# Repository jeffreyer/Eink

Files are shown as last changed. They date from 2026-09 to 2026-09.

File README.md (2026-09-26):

# MiniEink

**ESP32-C3 墨水屏设备固件** · 多屏适配 · Lua 模块化 · BLE 配置 · 深度休眠异步刷屏

> **English TL;DR** — Firmware for a small ESP32-C3 e-paper gadget. It drives three 1.54"
> panels (4-color 200x200 / 6-color 240x240 / black-white 200x200 SSD1681 with partial
> refresh), is configured over BLE from a WeChat mini program, runs user-installed Lua
> modules (gallery, quotes, countdown, calendar, tarot, ...), and uses a deep-sleep-first
> power model: the MCU issues the refresh command and sleeps immediately, waking only to
> power the panel down.

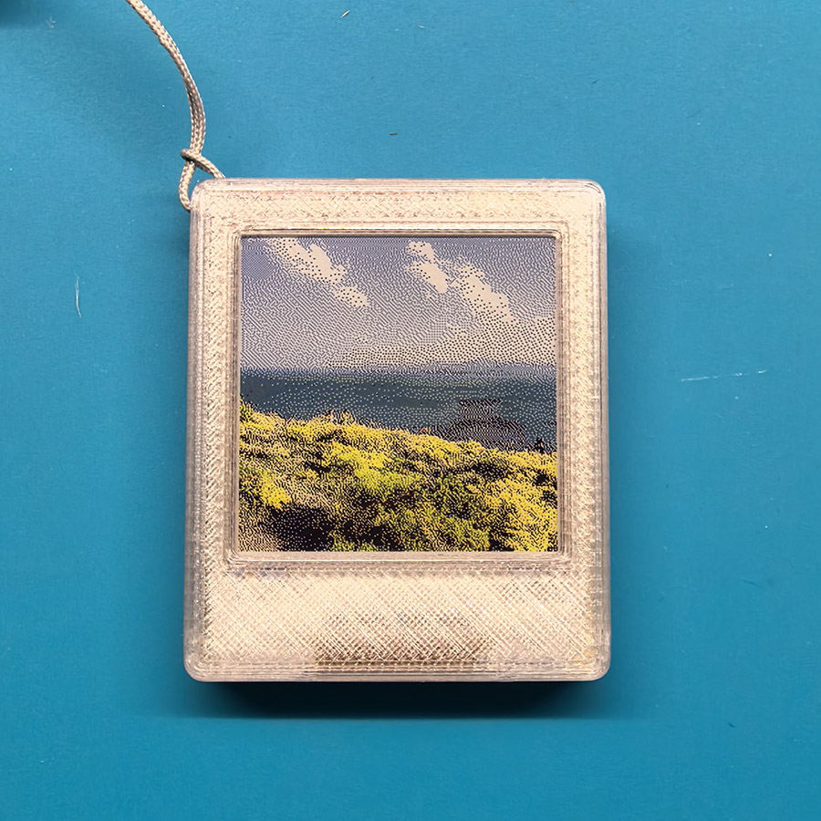
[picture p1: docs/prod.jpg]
 
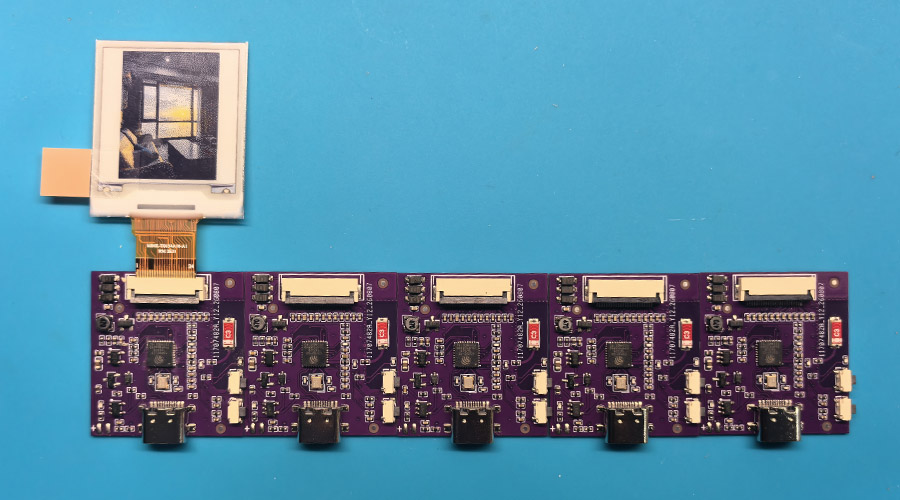
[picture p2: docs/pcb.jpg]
 
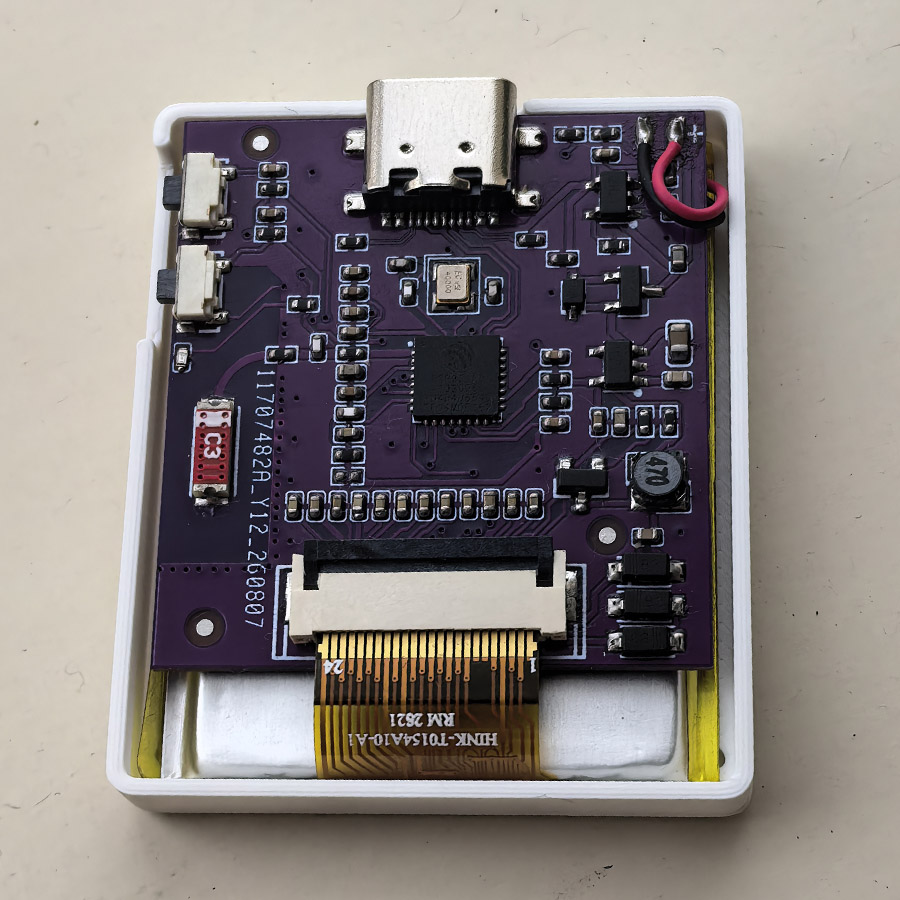
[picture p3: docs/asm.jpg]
 

---

## 目录

- [1. 项目简介](#1-项目简介)
- [2. 特性](#2-特性)
- [3. 硬件](#3-硬件)
- [4. 目录结构](#4-目录结构)
- [5. 快速开始](#5-快速开始)
- [6. 使用说明](#6-使用说明)
- [7. Lua 模块开发](#7-lua-模块开发)
- [8. 省电设计](#8-省电设计)
- [9. 分区表](#9-分区表)
- [10. 已知限制](#10-已知限制)
- [11. 第三方组件与许可](#11-第三方组件与许可)
- [12. 相关文档](#12-相关文档)
- [免责声明](#免责声明)
- [License](#license)

---

## 1. 项目简介

MiniEink 是一个基于 ESP32-C3 的多色墨水屏设备。设备平时处于**深度休眠**，休眠电流28uA，异步刷屏非常省电，靠按键或定时唤醒。所有交互（切换模块/条目、安装模块、改配置、上传图片）都通过 **BLE** 由微信小程序完成。

本项目包含设备源码/外壳3D设计和硬件设计全部开源文件。

## 2. 特性

**硬件**

- 外观尺寸：43\*36\*8.5mm
- 续航：200mA，休眠28uA，每次刷新40uA，每小时刷新一次，可续航4个月左右

**屏幕**

- 一套代码支持三种 1.54" 墨水屏，靠一个宏切换（见 3.2）
- 统一的显示接口：初始化、整帧刷新、刷白
- **异步刷屏**：发完刷新命令立即深度休眠，刷新结束后定时唤醒补断电——刷新期间的 MCU 电流从约 18 mA 降到接近 0
- **黑白屏局部刷新**：面板比对上一帧只驱动变化像素，约 0.3 s（全刷约 2s），不整屏闪黑；变化过大或连续局部刷到上限时自动全刷清残影
- **4色/6色屏刷新**：4色屏刷新约12秒，6色屏刷新约26秒
- 内置 GB2312 全量点阵字库（16x16 / 24x24），Lua 侧可直接显示中文

**系统**

- 模块化：内置相册 + 动态 **Lua 模块**，模块可启用/禁用、按键切换、定时唤醒刷新
- 统一休眠模型：任何模块执行完即休眠，没有常驻 `loop`，功耗可预期
- BLE 配置（NimBLE）：状态查询、模块安装、配置读写、图片上传/下载、校时
- 相册：图片存 SPIFFS，支持显示方向、循环播放、按键手动翻页
- 电池检测与低压保护（< 3.1 V 直接休眠）
- 省电细节：日常深度休眠、tickless idle / light sleep、BLE 断开即休眠、PWM 指示灯

## 3. 硬件

### 3.0 硬件制作注意事项

- Gerber.rar为已验证项目，直接打样即可，PCB厚度0.8mm
- 工程文件修改PCB挖空TypeC区域使用了TypeC沉板接口设计，厚度进一步降低0.8mm，但未作打样验证
- 如果使用6色屏请不要焊接R18电阻
- 参考上述图片组装硬件，最后胶水粘合上下外壳

### 3.1 规格与引脚

| 项目 | 规格 |
|---|---|
| 主控 | ESP32-C3（4 MB Flash，无 PSRAM） |
| 屏幕 | 1.54" 墨水屏，三种可选（见 3.2） |
| 按键 | KEY_UP / KEY_DOWN，低电平有效，可从深度休眠唤醒 |
| 指示灯 | 蓝色蓝牙开启 LED |
| 电池 | 3.85V 高压锂电，充满4.35V，ADC 分压采样（分压系数 2），< 3.1 V 保护性休眠 |
| 通信 | BLE 5（NimBLE-Arduino） |

| 信号 | GPIO |
|---|---|
| KEY_UP | 1 |
| KEY_DOWN | 2 |
| 电池 ADC | 0（ADC1_CH0） |
| EPD BUSY | 10 |
| EPD RST | 3 |
| EPD DC | 4 |
| EPD CS | 5 |
| EPD SCK | 6 |
| EPD MOSI | 7 |
| 蓝色 LED | 20 |

三种屏共用同一组 EPD 引脚，换屏只需改 `include/common.h` 的宏。

### 3.2 屏幕型号

| 型号 | 宏（`include/common.h`） | 分辨率 / 色深 | 帧大小 | 驱动 |
|---|---|---|---|---|
| 4 色（黑白黄红） | 两个宏都不定义 | 200x200 / 2bpp | 10000 B | `eink.cpp` + `Display_EPD_W21*.cpp` |
| 6 色（+蓝绿） | `#define INK6` | 240x240 / 4bpp | 28800 B | `eink6.cpp`（JD7601） |
| 黑白 | `#define INK_BW` | 200x200 / 1bpp | 5000 B | `eink_bw.cpp`（SSD1681，支持局部刷新） |

屏幕色数会通过 BLE 状态的 `ink` 字段上报（6 / 4 / 2），小程序据此选择图片格式。

## 4. 目录结构

```
src/
├── main.cpp              # 入口：按键扫描、唤醒判定、主循环
├── sleep_manager.cpp     # 深度休眠：唤醒源（按键/定时）与定时器配置
├── epd_async.cpp         # 异步刷屏调度：刷新中标记、补断电、兜底断电
├── eink.cpp / eink6.cpp / eink_bw.cpp   # 4 色 / 6 色 / 黑白屏驱动
├── Display_EPD_W21*.cpp  # 4 色屏底层时序
├── GUI/                  # GUI_Paint 绘图库（Scale 2/4/7 对应 1/2/4 bpp）
├── module_registry.cpp   # 模块注册表：内置模块 + 扫描 /spiffs 下的 Lua 模块
├── lua_hardware_api.cpp  # Lua 侧 API：display / time / config / sys
├── gallery.cpp           # 相册模块（列表、显示、旋转、循环）
├── ble_config.cpp        # BLE 服务：状态、配置、模块/图片上传、校时
├── battery.cpp           # 电池 ADC 采样与低压保护
├── cmd_handler.cpp       # 串口调试命令
└── time_calibration.cpp  # RTC 校时与时区保持

include/                  # 头文件（eink_display.h / epd_async.h / common.h ...）
lib/lua-5.4.7/            # Lua 解释器源码
data/                     # 烧录到 SPIFFS（modules 分区）
├── fonts/                # GB2312 16/24 点阵 + Unicode→GB2312 映射表
└── gallery.cfg           # 相册模块的配置定义
docs/LUA_SCRIPT_GUIDE.md  # Lua 模块开发与 API 完整文档
tools/                    # 字库生成、平台补丁等脚本
partitions.csv            # 分区表
platformio.ini            # PlatformIO 工程配置
PROJECT_HANDOFF.md        # 开发手记（中文，含大量实现细节与踩坑记录）
```

## 5. 快速开始

### 5.1 环境要求

- [PlatformIO](https://platformio.org/)（VSCode 插件或 Core CLI 6.x）
- Python 3（PlatformIO 自带；`tools/` 下的字库脚本需要 `Pillow`，仅重新生成字库时用到）
- 一块 ESP32-C3 设备（本项目用 `board = adafruit_qtpy_esp32c3` 作为板级变体，硬件为自定义板）

### 5.2 首次构建：给平台打补丁

工程用 `custom_sdkconfig` 打开电源管理 / tickless idle，pioarduino 平台在该配置下有两处
构建 bug（`lib_ignore = BLE` 会剪掉 IDF 的 bt 组件、库构建子环境读不到 `lib_deps`），
首次构建前先运行补丁脚本（可重复执行、可还原）：

```bash
python tools/pioarduino_patches.py            # 打补丁
python tools/pioarduino_patches.py --dry-run  # 只检查状态
python tools/pioarduino_patches.py --revert   # 还原
```

> 平台版本被 `platformio.ini` 固定在 pioarduino 55.03.38-1；升级平台后若脚本提示文本
> 不匹配，需要按脚本输出手工处理。

### 5.3 编译与烧录

```bash
pio run                        # 编译固件
pio run -t upload              # 烧录固件（USB）
pio run -t uploadfs            # 烧录文件系统：data/ → SPIFFS（modules 分区）
pio device monitor -b 115200   # 串口日志 / 调试命令
```

> 首次编译会按 `custom_sdkconfig` 全量重建 Arduino IDF 库，耗时较长（之后走缓存）。

要点：

- **固件和文件系统都要烧**：字库与配置定义在 `data/`，通过 `uploadfs` 写入 SPIFFS；
  只烧固件会出现中文显示为 `?`、模块没有配置项等问题。
- 修改 `data/` 后重新执行 `uploadfs` 会覆盖整个分区，设备上已上传的模块与相册图片
  请先备份（`pio run -t uploadfs` 不做合并）。
- 设备上运行时上传的模块与图片也都在同一块 SPIFFS 里，见 [第 9 节](#9-分区表)。

### 5.4 中文字库

`data/fonts/` 三个文件在运行时由 `lua_hardware_api.cpp` 直接读取：

| 文件 | 内容 |
|---|---|
| `gb2312_16.bin` | GB2312 全集 16x16 点阵，每字 32 B |
| `gb2312_24.bin` | GB2312 全集 24x24 点阵，每字 72 B |
| `gb2312_map.bin` | Unicode → GB2312 映射表（`[u32 count][count x (u16 u16)]`，按 Unicode 升序） |

重新生成（两个脚本二选一，输出都写到 `data/fonts/`）：

```bash
# A. 用 TTF 字体渲染（可换任意中文字体）
python tools/gen_gb2312_font.py --font C:/Windows/Fonts/NotoSansSC-VF.ttf

# B. 经典 HZK16 / HZK24S 点阵字库转换（源文件需自行准备，未随仓库发布）
python tools/convert_hzk.py tools/fonts/hzk_src/HZK16_ucdos.bin  data/fonts/gb2312_16.bin  32
python tools/convert_hzk.py tools/fonts/hzk_src/HZK24S_ucdos.bin data/fonts/gb2312_24.bin  72
```

## 6. 使用说明

### 6.1 按键

| 按键 | 短按 | 长按（按住 3 秒即触发） |
|---|---|---|
| KEY_UP | 上一项 | 开/关 BLE 配置模式 |
| KEY_DOWN | 下一项 | 切换到下一个已启用模块 |

设备默认深度休眠，按键可唤醒；唤醒后执行动作即再次休眠（BLE 配置模式除外）。

### 6.2 串口调试命令

| 命令 | 说明 |
|---|---|
| `ver` | 固件版本 + 编译时间 |
| `bat?` | 电池电压（mV） |
| `gettime?` | 当前时间 |
| `lsmod` | 列出已注册模块（类型 / 配置项数 / 是否启用） |
| `lsi` / `ls` | 列出 `/spiffs` / `/extflash` 文件 |
| `read <文件名>` | 打印 `/spiffs/<文件名>` 内容 |
| `rm <文件名>` | 删除 `/spiffs/<文件名>` |
| `dis <文本>` | 在屏幕上显示一段文本（验证屏幕与字库） |
| `white` | 整屏刷白 |
| `probe` | 打印面板 BUSY 电平时间线（适配新屏幕时测刷新时长与空闲极性） |
| `nvs` | 打印 NVS 中的键值 |
| `unbind` | 清除 BLE 绑定并重新生成密码 |
| `dfu` | 重启进入 ROM 下载模式（等同拉低 GPIO0 复位） |

### 6.3 通过 BLE 使用

1. 长按 KEY_UP 进入 BLE 配置模式（蓝色指示灯闪烁），设备以 `MiniEink` 广播；
2. 使用微信小程序*幻彩抽屉*连接；
3. 认证后即可查询状态、读写配置、安装 Lua 模块、上传相册图片；
4. 断开连接后设备立即深度休眠。

## 7. Lua 模块开发

模块 = 一个 `.lua` 脚本 + 可选的同名 `.cfg` 配置定义，放在 data 目录（`/data/<id>.lua`、`/data/<id>.cfg`），并通过上传文件系统命令传输到设备，设备启动时会扫描并注册为模块。
还可通过小程序市场下载安装，在小程序配置页启用/禁用。

```lua
-- @name: 纪念日倒计时
-- @version: 1.0.0
-- @author: your-name
-- @description: 显示距离目标日期的天数
-- @id: countdown

function setup()
  display.clear()
  display.text(10, 20, "距离目标还有", 3, 0)
  display.text(10, 60, "128 天", 4, 3)
  display.show()          -- 异步刷屏：发完刷新命令即可返回
end

-- 按键钩子（可选）：短按 KEY_UP / KEY_DOWN 时调用
function subpage_prev() end
function subpage_next() end
```

要点：

- `setup()` 每次唤醒（定时/按键）都会被调用一次，**画完请调用 `display.show()`**；
  模块的 `loop()` 不会被调用（统一休眠模型），周期刷新用配置项 `interval`
  （分钟，1~1440）交给系统定时唤醒。
- 屏幕尺寸由设备注册为全局量 `WIDTH` / `HEIGHT`（黑白屏与 4 色屏 200，6 色屏 240）。
- 颜色值统一为 `0=黑 1=白 2=黄 3=红 4=蓝 5=绿`；4 色与黑白屏会自动做合理映射
  （黑白屏把黄色映射为浅灰抖动，红/蓝/绿映射为黑）。
- 跨深度休眠的状态用 `sys.set_state()` / `sys.get_state()`（RTC 内存，掉电丢失）。
- 配置项读写用 `config.get()`；键名同时是 NVS 键名，**最长 15 字符**。

完整 API（`display.*` / `time.*` / `config.*` / `sys.*`、中文字库与排版注意事项）见
[`docs/LUA_SCRIPT_GUIDE.md`](docs/LUA_SCRIPT_GUIDE.md)。

配置定义 `.cfg`（决定小程序配置页渲染哪些控件）为 JSON 数组：

```json
[
  {
    "type": "select",
    "key": "interval",
    "label": "自动刷新",
    "options": [
      {"label": "关闭", "value": 0},
      {"label": "6小时", "value": 360}
    ],
    "default": 360
  }
]
```

## 8. 省电设计

**统一休眠模型**：设备没有常驻循环，模块执行完即 `esp_deep_sleep_start()`；唤醒源只有
按键（KEY_UP / KEY_DOWN）与定时器（模块配置的 `interval`）。蓝牙配置模式是唯一例外，
断开连接后立即休眠。

**异步刷屏**（`include/epd_async.h`）：墨水屏刷新由面板自己定时序，MCU 等待毫无意义。
所以流程是：

1. 模块调用 `display.show()` → 驱动发完刷新命令立即返回，并置一个 RTC 标记；
2. `enter_deep_sleep()` 看到该标记：只启用定时唤醒（禁按键唤醒，避免打断刷新），MCU 立刻休眠；
3. 定时唤醒后只做一件事：等刷新结束 → 关面板电源 → 面板深度休眠 → 继续休眠；
4. 若刷完没有休眠（例如 BLE 交互中）：主循环兜底，刷新结束后补一次断电。

| 屏型 | 刷新耗时 | 补断电唤醒窗口 |
|---|---|---|
| 6 色 240x240 | 20~30 s | 30 s |
| 4 色 200x200 | ~13.5 s | 22 s |
| 黑白全刷 | ~2 s | 4 s |
| 黑白局部刷 | ~0.3 s | 1.5 s |

深度休眠期间会 `gpio_hold` 住面板控制引脚（RST / DC / CS / SCK / MOSI），避免引脚浮空
干扰面板；唤醒补断电前先做一次“只复位、不等 BUSY”的复位，保证断电/深睡命令不被忽略。

**局部刷新（黑白屏）**：上一帧缓存在 RTC 内存（5000 B，带 CRC 校验），每次刷新把新帧写
`0x24`、上一帧写 `0x26` 作为基准，然后发 `0x22=0xCF` 局部刷新——面板只驱动有差异的像素。
变化像素超过 25%（`EPD_BW_PARTIAL_MAX_DIRTY_PCT`）或连续局部刷满 10 次
（`EPD_BW_PARTIAL_MAX_RUN`）时自动改走全刷清残影；阈值都在 `include/eink_bw.h`，
可按实测调整。

**其他**：`CONFIG_PM_ENABLE` + tickless idle 让 BLE 广播/等待期间自动进入 light sleep；
BUSY 轮询间隔 ≥ 20 ms 才能让 CPU 睡进 light sleep；指示灯用 1 kHz / 5% PWM 代替常亮。

## 9. 分区表

`partitions.csv`（4 MB Flash）：

| 分区 | 类型 | 偏移 | 大小 | 用途 |
|---|---|---|---|---|
| `nvs` | data/nvs | 0x9000 | 20 KB | 配置、绑定状态、密码 |
| `otadata` | data/ota | 0xE000 | 8 KB | 预留 |
| `app0` | app/ota_0 | 0x10000 | 992 KB | 固件 |
| `modules` | data/spiffs | 0x108000 | 约 3.0 MB | SPIFFS：字库、模块 `.lua/.cfg`、相册图片 |

## 10. 已知限制

- 局部刷新目前只有**黑白屏**支持；4 色与 6 色驱动仍是整屏刷新。
- 换屏幕型号后，相册里旧格式的图片无法显示（设备按字节数校验并拒绝），需要重新上传。
- 局部刷新会积累残影，因此有“每 N 次 / 变化过大自动全刷”的策略，做不到“永不闪屏”。
- 部分面板的 BUSY 引脚在读不到空闲电平（例如 MCU 深睡醒来后一直为低），因此补断电逻辑
  以时间为保证、不依赖 BUSY；`probe` 命令可用于确认某块屏的 BUSY 行为。
- 当前固件只有一个 app 分区，**不支持 OTA**，升级需要重新烧录。

## 11. 第三方组件与许可

| 组件 | 说明 / 许可 |
|---|---|
| [Lua 5.4.7](lib/lua-5.4.7) | 源码在 `lib/lua-5.4.7`，MIT |
| [NimBLE-Arduino](https://github.com/h2zero/NimBLE-Arduino) | BLE 栈，Apache-2.0（PlatformIO 依赖） |
| [FastLED](https://github.com/FastLED/FastLED) | PlatformIO 依赖，MIT |
| GUI_Paint / 4 色屏时序 | 面板原厂示例代码（Good Display 系列），保留原貌 |
| 6 色（JD7601）/ 黑白（SSD1681）驱动 | 由面板原厂示例移植（含初始化时序与波形表） |
| `data/fonts/*.bin` | 由经典 HZK16 / HZK24S 点阵字库转换（来源见 `tools/convert_hzk.py`） |

## 12. 相关文档

- [`docs/LUA_SCRIPT_GUIDE.md`](docs/LUA_SCRIPT_GUIDE.md)：Lua 模块开发完整指南
  （模块格式、`display`/`time`/`config`/`sys` API、中文字库与排版注意事项）
- [`PROJECT_HANDOFF.md`](PROJECT_HANDOFF.md)：开发手记，含屏幕适配、省电实测、
  BLE 分块传输、小程序前端交互等实现细节与踩坑记录（中文）
- `python tools/pioarduino_patches.py --dry-run`：检查构建平台补丁状态

## 免责声明

本项目是个人自制的开源固件工程，按“现状”提供，不保证适用于任何特定用途。自行打样、
焊接、连接锂电池时请注意安全（保护板、极性、避免短路），因使用本工程造成的设备损坏或
数据丢失由使用者自行承担。

## License
- 固件代码: GPLv3
- 硬件设计: CC BY-NC-SA 4.0

商业使用需获得作者书面许可。

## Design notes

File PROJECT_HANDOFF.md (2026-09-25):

# 项目交接文档 - MiniEink墨水屏设备

## 项目概述

这是一个基于ESP32-C3的墨水屏设备项目，包含设备端固件和微信小程序前端。设备通过BLE与小程序通信，支持模块化配置和相册管理功能。

**设备型号**: MiniEink (Adafruit QT Py ESP32-C3)  
**显示屏**: 三个版本（`include/common.h` 中三选一）
- 4色屏（都不定义宏）：200x200 2bpp（黑、白、黄、红）
- 6色屏（`INK6` 宏）：1.54寸 240x240 JD7601 4bpp（黑、白、黄、红、蓝、绿）
- 黑白屏（`INK_BW` 宏）：1.54寸 200x200 SSD1681 1bpp（黑、白）
  - **当前为 6 色屏模式（`#define INK6` 已开启）**；换黑白屏注释 `INK6`、打开 `INK_BW`
  - 三个驱动各自整体由宏保护（文件顶部先 `#include "common.h"` 才能看到宏），
    同一时刻只有一个驱动参与编译，避免重复定义 `BlackImage`/`gui_drawtext`
**刷新时间**: 黑白约2秒；4色约12秒；6色约30-40秒（驱动内 BUSY 超时上限 40 秒）。
三者都走异步刷屏：发出刷新命令后 MCU 立刻深度休眠，刷新结束由定时唤醒补断电  
**通信方式**: BLE (NimBLE)  
**开发环境**: PlatformIO + Arduino Framework  
**前端**: 微信小程序

---

## 6色屏适配（当前主线）

新版硬件：6色 1.54寸 240x240 墨水屏（JD7601 驱动，4bpp 打包，每字节 2 像素），
并新增 KEY_UP / KEY_DOWN 两个实体按键。固件通过 `include/common.h` 中的 `#define INK6`
区分 6 色 / 4 色编译模式。

### 引脚（6色屏）

| 信号 | GPIO |
|---|---|
| KEY_UP | 1 |
| KEY_DOWN | 2 |
| BLE_LIGHT | 20 |
| EPD BUSY | 10 |
| EPD RST | 3 |
| EPD DC | 4 |
| EPD CS | 5 |
| EPD SCK | 6 |
| EPD MOSI | 7 |

### 颜色编码（设备端，与 JD7601 面板码一致）

| 颜色 | 半字节(nibble) | 字节(2像素) |
|---|---|---|
| 黑 | 0x0 | 0x00 |
| 白 | 0x1 | 0x11 |
| 黄 | 0x2 | 0x22 |
| 红 | 0x3 | 0x33 |
| 蓝 | 0x5 | 0x55 |
| 绿 | 0x6 | 0x66 |

**前端色板校准**（`image-editor.js getPalette()` / `imageProcessor.js rgbTo6ColorCode()`，
用于预览显示与误差扩散的目标色，非设备端帧码）：

| 颜色 | 名义值 | 校准值（实拍6色条估计） |
|---|---|---|
| 白 | 255,255,255 | 240,238,228（暖白） |
| 黑 | 0,0,0 | 25,25,30 |
| 红 | 255,0,0 | 210,65,48（偏暗砖红） |
| 黄 | 255,255,0 | 235,230,55 |
| 蓝 | 0,0,255 | 23,100,182（偏暗藏蓝） |
| 绿 | 0,128,0 | 50,118,88（偏橄榄） |

### 绘制与刷新链路

- 画布：`BlackImage[28800]`（240x240，4bpp），由 `eink6.cpp` 定义
- 绘制：复用 `GUI_Paint` 的 `Paint_SetScale(7)`（4bpp，2像素/字节，高位在前），
  与 JD7601 帧格式逐字节一致，`lua_hardware_api.cpp` 在 `INK6` 下自动切换
- 刷新：`display.show()` → `epdDisplayImage()`（写帧 0x10 → 刷新 0x12 后立即返回，
  断电与面板休眠由 `epd_async` 调度）
- 4色屏代码在 `INK6` 下通过 `#ifndef INK6` 整体跳过（`eink.cpp`）

### Lua 颜色值

`0=黑, 1=白, 2=黄, 3=红, 4=蓝, 5=绿`（4色屏仅支持 0-3）。
`WIDTH` / `HEIGHT` 全局量由固件注册，`INK6` 下自动为 240。

### 按键功能（`main.cpp check_btn`）

| 按键 | 短按 | 长按(3秒) |
|---|---|---|
| KEY_UP | 模块"上一项"钩子（`subpage_prev`，相册=上一张、名言=上一条）；无钩子则 subpage-1 | 开关 BLE 配置 |
| KEY_DOWN | 模块"下一项"钩子（`subpage_next`，相册=下一张、名言=下一条）；无钩子则 subpage+1 | 切换下一个启用模块（`module_registry_next_enabled`，按住3秒即触发，并保存当前模块） |

模块可在 `module_descriptor_t` 注册 `subpage_next/subpage_prev` 自定义按键行为
（`gallery` 注册为上一张/下一张；**Lua 模块在脚本中定义同名函数即可注册**，
如名言 `subpage_next/subpage_prev`；其他模块默认 subpage ±1，互不影响）。
统一休眠模型下，按键唤醒**不执行模块 setup**：系统记录唤醒按键，由 `check_btn`
判定短按/长按后执行对应动作并休眠（短按 → 上一项/下一项钩子，长按 → 切模块/开 BLE）。
Lua 按键钩子被调用时若模块未加载（按键唤醒跳过了 setup），系统会**只加载脚本、
不执行 setup 绘制**，再由钩子自行绘制。

### BLE 状态字段

`get_status` 回传 `"ink"` 为墨水屏色数（6 / 4 / 2），小程序据此选择图片格式
（6色：240x240 4bpp / 28,800 字节；4色：200x200 2bpp / 10,000 字节；
黑白：200x200 1bpp / 5,000 字节）。

**电量字段**：状态 JSON 只回传 `"battery_mv"`（分压后电压，分压系数2），
百分比由前端自行换算（3300mV~4200mV → 0-100%，`bluetooth.js applyBatteryPercent()`）。
首次状态请求时触发一次 ADC 采样。

---

## 墨水屏驱动（三选一）与统一接口

三种屏型通过 `include/common.h` 里的宏切换，调用点统一走 `include/eink_display.h`
暴露的接口，不再各自写条件编译：

| 屏型 | 宏 | 帧缓冲 | 驱动实现 |
|---|-----|---|---|
| 4 色 200x200 2bpp | 无 | `BlackImage[10000]` | `eink.cpp` + `Display_EPD_W21*.cpp` |
| 6 色 240x240 4bpp | `INK6` | `BlackImage[28800]` | `eink6.cpp` |
| 黑白 200x200 1bpp | `INK_BW` | `BlackImage[5000]` | `eink_bw.cpp`、`eink_bw.h` |

统一接口（各驱动的 `.cpp` 内实现，见 `include/eink_display.h`）：

- `eink_display_init()`：初始化 SPI 与面板，`setup()` 调用一次
- `eink_display_frame()`：把 `BlackImage` 整帧刷到屏幕（**异步**：发完刷新命令即返回）
- `eink_display_white()`：全屏刷白
- `extern unsigned char BlackImage[ALLSCREEN_BYTES]`：当前屏型的画布缓冲

### 异步刷屏调度层（`include/epd_async.h` + `src/epd_async.cpp`）

三种屏共用同一套“发完刷新命令就休眠”的省电机制，驱动只实现两个钩子：

| 钩子 | 作用 |
|---|---|
| `epdPanelIsIdle()` | 刷新是否已结束（读 BUSY 空闲电平） |
| `epdPanelPowerOff()` | 关闭面板电源 + 面板深度休眠（假定刷新已结束） |

调度层提供：

| 接口 | 时机 | 行为 |
|---|---|---|
| `epdAsyncMarkStarted()` | 驱动发完刷新命令后 | 置 RTC 标志，函数立即返回 |
| `epdAsyncIsPending()` | 各处判断 | 是否有刷新进行中（跨深度休眠保持） |
| `epdAsyncWaitPrevious()` | 新一帧开始前 | 上一帧未刷完先等它结束，避免 reset 打断刷新 |
| `epdAsyncPowerOffNow()` | 定时唤醒补断电 / 进 BLE 前 | 断电 → 面板休眠（**不等 BUSY**，几十毫秒返回） |
| `epdAsyncMaintain()` | 主循环 | 未休眠时兜底：刷新结束且过了延迟才断电（**非阻塞**，不拖慢 BLE） |
| `epdAsyncPrepareSleep()` | 进深度休眠前 | 刷新中则 `gpio_hold` 住面板控制脚，见下 |
| `epdAsyncReleasePins()` | 开机初始化墨水屏前 | 释放上次休眠保持的引脚 |

完整流程（三个屏型一致）：

1. 模块 `setup` 绘制 → `eink_display_frame()` 发出刷新命令 → 置标志后立即返回；
2. `enter_deep_sleep()` 发现标志：只启用 `EPD_ASYNC_REFRESH_SLEEP_S` 秒定时唤醒
   （禁用 GPIO 唤醒，避免按键中途唤醒打断刷新），MCU 立刻休眠；
3. 定时唤醒后 `setup()` 走快路径：`eink_display_init()` 只初始化总线
   （**pending 时不 reset 面板**）→ `epdAsyncPowerOffNow()` 直接断电
   （唤醒时刻按刷新时长选取，**不再依赖 BUSY 判空闲**）→ 清标志 → 继续休眠；
4. 若没休眠（BLE 交互 / 上电待机）：主循环 `epdAsyncMaintain()` 在刷新结束、
   且超过 `EPD_PANEL_POWEROFF_DELAY_MS` 后补一次断电；BUSY 读不到空闲电平时，
   到达 `EPD_ASYNC_FORCE_POWEROFF_MS` 也会兜底断电（非阻塞，不会卡住 loop）。

进入 BLE 前（`ble_config_init`）：面板没在刷新就立即断电 + 面板休眠（按键唤醒进
BLE 时面板刚 init 过，不断电会持续耗电）。这里**也不能等 BUSY**：面板处于睡眠/非
初始化态时 BUSY 一直是忙电平（实测进 BLE 时 BUSY=0，白等 3 秒），所以直接走
`epdAsyncPowerOffNow()`；正在刷新则交给主循环补断电（4 色要 13.5 秒、6 色要 30 秒，
阻塞会让 BLE 迟迟不广播）。

同理，6 色驱动断电阶段的 BUSY 等待上限从 10 秒收到 `POWEROFF_WAIT_MS`（2 秒）兜底。

注意：异步刷新窗口内**只启用定时唤醒、禁用 GPIO 唤醒**，这段时间（黑白 6 秒 /
4 色 22 秒 / 6 色 30 秒）按键不会被响应——这是为了避免按键打断刷新，代价与
6 色屏原有行为一致。

各屏参数（定义在各自驱动头文件，调度层取默认值兜底）：

| 屏型 | 全刷耗时 | `EPD_ASYNC_REFRESH_SLEEP_S` | `EPD_PANEL_POWEROFF_DELAY_MS` | `EPD_ASYNC_WAIT_TIMEOUT_MS` |
|---|---|---|---|---|
| 6 色 240x240 | 20~30s | 30 | 3000 | 5000 |
| 4 色 200x200 | ~13.5s（实测） | 22 | 13000 | 3000 |
| 黑白 200x200 | 全刷 ~2s / 局部刷 ~0.3~0.5s | 4（全刷）/ 1.5（局部刷，`EPD_BW_*_REFRESH_MS`） | 3000 | 3000 |

（`EPD_ASYNC_FORCE_POWEROFF_MS`：未休眠时的兜底断电时间，6 色 40s / 4 色 20s / 黑白 6s）

**BUSY 只是优化，时间才是保证**：定时唤醒路径完全不等 BUSY；主循环兜底路径优先看
BUSY，读不到空闲电平则按时间兜底。所以即便某块屏 BUSY 引脚不可读，也不会出现长时间
卡住或面板一直通电。

**四色板实测（`probe` 命令 + 唤醒探针）**：醒着刷一次全白 **13.5 秒**完成
（BUSY 忙=0 / 空闲=1，极性正确、引脚正常）；但 MCU 深度休眠期间面板控制 IC 会
进入非初始化状态，唤醒后 BUSY 一直为 0，**而屏幕内容显示正确**（墨水屏双稳态，
图像不依赖 IC 供电/状态）。因此四色屏的补断电流程改为：

1. 唤醒后不等 BUSY，也不做整屏初始化（`lcd_chkstatus()` 是死等，绝不能进）；
2. `EPD_reset_only()` 只做一次复位（不等 BUSY），把控制 IC 拉回已知状态；
3. `EPD_poweroff_sleep()` 发 0x02 断电 + 0x07 面板深睡。

复位不会影响已显示画面（双稳态），但能保证断电/深睡命令不被忽略。四色刷新窗口据此
放宽到 22 秒（实测 13.5 秒 + 余量）。

`EPD_ASYNC_WAIT_TIMEOUT_MS` 是“等 BUSY 变空闲”的兜底上限：唤醒时刻本就选在刷新完成
之后，这里只防意外，超时后**照常断电**（面板会在下一帧初始化时重新复位，不会损坏）。

### 深度休眠期间保持面板控制脚（`gpio_hold`）

MCU 深度休眠时 GPIO 会浮空：EPD 的 RST/CS/SCK/MOSI 浮空可能被干扰，甚至把面板拉进
复位态，表现就是**唤醒后 BUSY 一直报忙**、补断电流程只能走到超时（曾出现 60 秒延迟）。
因此在异步刷屏进入休眠前（`epdAsyncPrepareSleep()`）把 RST/DC/CS/SCK/MOSI 拉到空闲电平
并 `gpio_hold_en()` + `gpio_deep_sleep_hold_en()` 固定住，开机时 `epdAsyncReleasePins()`
（`main.cpp` 里，早于 SPI 初始化）释放。

补断电 / 进 BLE 前都不再等 BUSY，因此日常日志不会再出现 `wait idle`。唯一还会
等 BUSY 的地方是“新一帧开始前，上一帧仍在刷新”的同步点（`epdAsyncWaitPrevious()`），
它同样带短超时并打印原始电平：

```
[EPD] sync: waiting previous refresh to finish
[EPD] wait idle: BUSY raw=0                 # 进入等待时 BUSY 读数
[EPD] wait idle timeout (3000 ms), BUSY raw=0 -> power off anyway
```

### BUSY 时间线探针（临时诊断）

四色板实测“唤醒后 BUSY 恒为 0”（尽管画面已刷新完成），需要用探针确认 BUSY 的
真实空闲极性与刷新时长。两处探针由 `EPD_PROBE_BUSY_ON_BOOT` 控制，**默认已置 0**
（日常运行不打印、不白屏刷屏）：

- 置 1 时：上电冷启动自动跑一次时间线，并且每次唤醒打印唤醒后 BUSY 原始电平
  （在任何 GPIO/SPI 初始化前、初始化后各一次）；
- **串口命令 `probe`**：不受开关影响，随时手动重跑时间线（换新屏幕板卡时用来确认
  刷新时长与 BUSY 极性）。

输出形如：

```
[EPD] probe: cold boot, measuring BUSY timeline
[EPD] probe: t=0 ms BUSY=0 idle=0
[EPD] probe: t=1000 ms BUSY=0 (stable)
...
[EPD] probe: t=12000 ms BUSY=1 idle=1     ← 翻转点 = 真实刷新时长 + 空闲电平
[EPD] probe: BUSY timeline end
```

据此可判断：翻转后为 1 → 现有 `epdPanelIsIdle()`（`BUSY==1`）正确，问题只在
“唤醒时刷新确实还没结束”；翻转后为 0 → 该屏空闲电平为低，把 `epdPanelIsIdle()`
反过来；始终不变 → 该脚没有反映刷新状态（走线/引脚不对），保持纯时间兜底。

### 1.54 寸黑白屏（`INK_BW`）

- 控制器 SSD1681 兼容，1bpp（1 字节 8 像素，**bit=1 为白**），帧 5000 字节
- 驱动移植自 `ESP32-C6-ePaper-1.54` 例程 `port_display.cpp`，去掉了 LVGL 与
  `esp_lcd_panel_io`，改用项目统一的 Arduino SPI + GPIO；全刷波形表（159 字节）
  原样保留
- 引脚与 6 色屏硬件一致（MOSI=7 / CLK=6 / BUSY=10 / DC=4 / CS=5 / RST=3），
  定义集中在 `include/eink_bw.h`，换硬件只改这一处
- 刷新流程：`0x12 SWRESET` → 驱动输出/数据入口/窗口/Border/温度/LUT →
  `0x24` 写帧 → `0x22 0xC7 + 0x20` 触发刷新后**立即返回**（约 2 秒刷新期间 MCU
  进入深度休眠，5 秒后唤醒补断电）；`epdPanelPowerOff()` 里 `0x10 0x01` 让面板
  深度休眠
- `gui_drawtext()` 调试命令、"white" 串口命令均已实现

**颜色映射（Lua 颜色值 → 黑白屏）**：`1 白 → 白`、`2 黄 → 浅灰抖动`、
`0/3/4/5 → 黑`。抖动由 `GUI_Paint` 的 Scale=2 分支实现（4x4 Bayer 有序抖动，
中间灰常量 `GRAY_LIGHT/GRAY_MID/GRAY_DARK` 定义在 `include/GUI_Paint.h`），
这样原本用黄色的高亮块在黑白屏上不会直接消失。

### 黑白屏局部刷新（自动全刷/局部刷切换）

SSD1681 支持局部刷：面板比对 `0x26`（基准旧图）与 `0x24`（新图），**只驱动有差异的
像素**，波形短（约 0.3~0.5s，全刷约 2~2.6s），且不会整屏闪黑。上层 API 不变，
由驱动自动判断，模块脚本无需改动。

本项目每次刷完都深度休眠、复位补断电，面板 RAM 不能指望保留，所以“上一帧”放在
**RTC 内存**里：

| 项 | 说明 |
|----|---|
| `s_prev_frame[5000]` | RTC_DATA_ATTR；C3 RTC 数据区约 8KB，本工程其余只用了几十字节（链接后 `.rtc.data` ≈ 5.1KB） |
| 有效性 | `s_prev_marker` + `s_prev_frame` 的 CRC32（ROM CRC）校验，掉电/残缺 → 校验不过 → 全刷 |
| 连续局部刷计数 | `s_partial_run`（RTC），到 `EPD_BW_PARTIAL_MAX_RUN`（10 次）强制全刷一次清残影 |

刷新决策（`main.cpp`/模块无需感知）：

```
变化像素 > EPD_BW_PARTIAL_MAX_DIRTY_PCT(25%)  → 全刷（0x24+0x26 写新帧 + 0x22 0xC7）
无基准 / CRC 校验失败 / 连续局部刷达 10 次  → 全刷
其余                                       → 局部刷（进局部模式 → 0x24 新帧 + 0x26 上一帧 → 0x22 0xCF）
```

局部刷新流程照搬原厂 `EPD_Init_Partial()`（局部波形表 `WF_PARTIAL_1IN54` + `0x37` +
`0x3C=0x80` + `0x22=0xC0`），只是省掉它前面的复位（本驱动每帧都会整屏初始化）。
与原厂不同的一点：**每帧都把上一帧写进 `0x26`**（原厂只在建基图时写一次），这样
每次只驱动“相对上一帧”真正变化的像素，残影最小。

局部刷的补断电窗口也短：`EPD_BW_PARTIAL_REFRESH_MS`（1.5s）vs
`EPD_BW_FULL_REFRESH_MS`（4s）——面板通电时间与刷新电流都明显下降。

日志（用于观察与调参）：

```
[EPD-BW] full refresh: 40000 px changed (100.00%), partial_run was 0
[EPD-BW] partial refresh: 512 px changed (1.28%), run 1/10
```

**前端已配套（小程序）**：设备上报 `"ink": 2`，图片格式为 200x200 1bpp =
**5000 字节**，`bit=1` 白、`bit=0` 黑。前端统一从 `app.getInkSpec()` 取规格：

| 位置 | 改动 |
|---|---|
| `app.js` | 新增 `getInkSpec()`：按 `ink` 返回 `{width,height,bits,bytes,isMono}`（6→240/4bit/28800，2→200/1bit/5000，4→200/2bit/10000） |
| `pages/image-editor` | 黑白屏用 2 色色板（白 `0x01`/黑 `0x00`）+ 亮度阈值 128 + 误差扩散产生灰阶；按 1bpp 高位在前打包；预览标题为“黑白预览”，隐藏无意义的“冷暖”滑块 |
| `pages/gallery` | 缩略图解码支持 1bpp；缓存键改为按屏型隔离（`gallery_image_cache_v3_ink<色数>`），换屏后不再沿用旧格式缩略图 |

---

## 目录结构

### 设备端 (`d:\Projects\Eink`)

```
src/
├── main.cpp              # 主程序入口，loop和setup
├── ble_config.cpp        # BLE通信核心（NimBLE），包含分块传输
├── cmd_handler.cpp       # 串口命令处理器（含 white/dis 调试命令）
├── module_registry.cpp   # 模块注册表（含 Lua 动态模块加载）
├── sleep_manager.cpp     # 休眠管理（深度睡眠，KEY_UP/KEY_DOWN 唤醒）
├── gallery.cpp           # 相册功能（含 1bpp/2bpp/4bpp 旋转）
├── eink.cpp              # 4色屏驱动封装（INK6/INK_BW 下不编译）
├── eink6.cpp             # 6色屏 JD7601 驱动 + 6色画布 BlackImage
├── eink_bw.cpp           # 黑白屏 SSD1681 驱动 + 1bpp 画布 BlackImage
├── epd_async.cpp         # 异步刷屏调度（RTC pending 标志 / 补断电 / 兜底）
├── lua_hardware_api.cpp  # Lua display API（绘制/中文渲染/刷新）
├── Display_EPD_W21.cpp   # 4色屏底层驱动（PIC_write_ram / EPD_update_async / 断电休眠）
└── GUI/                  # GUI_Paint 绘制库（Scale 2=1bpp, 4=2bpp, 7=4bpp）

include/
├── ble_config.h          # BLE接口定义
├── cmd_handler.h
├── module_registry.h
├── sleep_manager.h
├── gallery.h
├── eink.h                # 4色屏参数（200x200）
├── eink6.h               # 6色屏参数（240x240）+ 颜色常量
├── eink_bw.h             # 黑白屏参数（200x200, 1bpp）+ 引脚
├── eink_display.h        # 三种屏型统一显示接口
├── epd_async.h           # 异步刷屏调度接口 + 各屏参数
├── image.h               # 6色测试图（调试用）
└── GUI_Paint.h

data/
├── gallery.cfg           # 相册配置定义（display_mode, cycle_interval；rotation 已移至模块页全局配置）
├── quotes.cfg            # 名言警句配置定义（interval 切换间隔，分钟）
├── quotes.lua            # 名言警句模块（内置 431 条国内外名言）
├── countdown.lua         # 纪念日倒计时模块
└── fonts/                # GB2312 全量点阵字库（16/24px + 映射表）

platformio.ini            # PlatformIO配置
```

### 前端 (`d:\Projects\jeff\WeChatProjects\pix`)

```
pages/
├── modules/              # 模块列表页（首页TabBar）
├── module-config/        # 模块配置详情页
├── gallery/              # 相册管理页（仅MiniEink设备，TabBar）
├── image-editor/         # 图片编辑页（按设备 ink 字段选黑白/4色/6色格式）
├── device-connect/       # 设备扫描连接页
├── market/               # 模块市场页（TabBar）
└── profile/              # 个人中心页（TabBar）

utils/
├── bluetooth.js          # ⭐ BLE通信核心，统一管理所有BLE交互
└── imageProcessor.js     # 图片处理工具（4色/6色量化与打包）

app.js                    # 全局应用配置
app.json                  # 小程序配置（TabBar等）
```

---

## 技术栈

### 设备端

| 组件 | 版本/说明 |
|---|---|
| 平台 | PlatformIO |
| 框架 | Arduino (ESP32 5.5.4) |
| BLE库 | NimBLE-Arduino 2.5.0 |
| 显示 | GUI_Paint 绘制库；4色屏 Display_EPD_W21 / 6色屏 eink6 (JD7601) |
| Lua | lua-5.4.7（动态模块脚本） |
| 编译命令 | `d:\.platformio\penv\Scripts\platformio.exe run`（⚠️ 仅编译，不上传） |

### 前端

| 组件 | 说明 |
|---|---|
| 框架 | 微信小程序 |
| 基础库 | 2.9.0+ |
| 权限 | scope.bluetooth, scope.writePhotosAlbum |
| 云开发 | cloud1-d3gxxnyov88776090 |

---

## BLE通信协议

### Service & Characteristics

```
Service UUID:  8C0B8A10-7E3D-4DF7-9A2A-1D8D46F8B100
Config Char:   8C0B8A11-7E3D-4DF7-9A2A-1D8D46F8B100 (WRITE)
Status Char:   8C0B8A12-7E3D-4DF7-9A2A-1D8D46F8B100 (READ | NOTIFY)
```

### 命令格式 (JSON)

#### 小程序 → 设备 (通过 Config Characteristic)

```javascript
// 模块相关
{"manifest": 0}                    // 获取模块0的配置清单
{"module": 0, "config": {...}}     // 设置模块0的配置

// 相册相关（仅MiniEink）
{"gallery_list": true}             // 获取图片列表
{"gallery_upload_start": true, "filename": "...", "size": 28800, "chunk_size": 336} // 开始上传（6色=28800，4色=10000）
{"gallery_upload_chunk": true, "index": 0, "data": "base64..."}  // 上传数据块（带索引，按固定偏移落位）
{"gallery_upload_progress": true}                                // 查询已连续接收的字节数（丢包补齐用）
{"gallery_upload_complete": true}                                // 上传完成（返回真实保存结果 ok/error）
{"gallery_get": true, "filename": "..."}                         // 获取图片
{"gallery_show": true, "filename": "..."}                        // 显示图片
{"gallery_delete": 2}                                            // 删除索引2

// 系统相关
{"get_status": 0}                  // 获取状态（支持分页）
```

`get_status` 响应包含 `"ink"` 字段（4 或 6），小程序端据此区分图片格式与编辑尺寸。

#### 设备 → 小程序 (通过 Status Characteristic)

```javascript
// Manifest响应
{"id": "clock", "name": "时钟", "configs": [...]}

// Gallery列表响应
{"images": [{"filename": "img_123.img", "size": 5000}, ...]}

// Gallery图片响应
{"image_data": "base64encoded..."}

// 上传进度响应（gallery_upload_progress）
{"ok": true, "received": 13104, "size": 28800}  // received=从0起连续收到的字节数

// 上传保存结果回执（gallery_upload_complete，前端 uploadComplete 等待此响应）
{"ok": true}                                   // 保存成功
{"ok": false, "error": "Save failed"}          // 保存失败（如磁盘满）

// 分块传输（大数据自动分块，每块约200字节）
{"chunk": 0, "total": 5, "data": "..."}
{"chunk": 1, "total": 5, "data": "..."}
// ...
{"chunk": 4, "total": 5, "data": "..."}
```

### 分块传输机制

**设备端发送** (`ble_config.cpp::set_status()`):
- 自动检测数据大小
- 超过200字节自动分块
- 每块包含 `chunk`、`total`、`data` 字段

**小程序接收** (`bluetooth.js`):
- 全局监听器统一接收
- 根据数据类型分发到对应callback：
  - `manifestCallback` - 模块配置
  - `galleryListCallback` - 图片列表
  - `galleryImageCallback` - 单张图片
  - `uploadResultCallback` - 图片上传进度/保存结果回执（含 `ok` 字段的状态）
- 自动合并分块，验证完整性

**图片上传（前端 → 设备，`gallery.js uploadImageToDevice`）**:
- 336 字节/块（base64 448 字符 + JSON ≈ 487，适配 512 MTU），每块带 `index`
- 设备端在 **BLE 回调中直通处理**图片上传命令（绕过单槽 `s_pending_cmd` 队列，
  避免高频分块覆盖丢块），按 `index*chunk_size` 固定偏移落位，重复/乱序块忽略
- 前端 15ms 块间隔 + 写失败退避重试；发完后轮询 `gallery_upload_progress`，
  只有进度连续无变化才补发缺失后缀（最多8轮）
- 全部收满后才发 `gallery_upload_complete`，并等待设备端真实保存结果
  （`uploadComplete()`，15 秒超时），失败则提示设备返回的错误
- 预期耗时：28800 字节约 2-3 秒（原 256 字节/100ms 限速版约 11 秒）

---

## 核心架构

### BLE通信架构 ⭐

**关键原则**：所有BLE数据接收统一由 `bluetooth.js` 管理，**页面不得直接注册监听器**。

#### bluetooth.js 核心组件

```javascript
class Bluetooth {
  // 全局监听器（仅此一个）
  setupGlobalListener() {
    wx.onBLECharacteristicValueChange((res) => {
      // 解析数据
      const status = this.parseStatus(res.value);
      
      // 根据数据类型分发
      if (status.chunk !== undefined) {
        // 分块数据，分发给等待的callback
        if (this.manifestCallback) this.manifestCallback(status);
        if (this.galleryListCallback) this.galleryListCallback(status);
        if (this.galleryImageCallback) this.galleryImageCallback(status);
      } else if (status.id && status.configs) {
        // manifest数据
        if (this.manifestCallback) this.manifestCallback(status);
      } else if (status.images) {
        // gallery list数据
        if (this.galleryListCallback) this.galleryListCallback(status);
      } else if (status.image_data) {
        // gallery image数据
        if (this.galleryImageCallback) this.galleryImageCallback(status);
      } else if (status.ok !== undefined && this.uploadResultCallback) {
        // 上传进度/保存结果回执
        this.uploadResultCallback(status);
      } else {
        // 普通状态更新
        app.globalData.deviceStatus = status;
      }
    });
  }
  
  // 统一接口方法
  async getModuleManifest(index) { /* 设置manifestCallback */ }
  async getGalleryList() { /* 设置galleryListCallback */ }
  async getImageFromDevice(filename, onProgress) { /* 设置galleryImageCallback */ }
}
```

#### 页面使用方式

```javascript
// ✅ 正确 - 使用bluetooth.js的统一接口
const result = await bluetooth.getGalleryList();

// ❌ 错误 - 不要在页面直接注册监听器
wx.onBLECharacteristicValueChange((res) => {
  // 这会导致监听器泄漏！
});
```

---

## 重要问题修复记录

### 问题1: 相册模块点击转圈超时

**现象**: 第二次点击相册模块配置时，一直转圈，超时失败。

**根因**: 
- `gallery.js` 在 `loadImageList()` 中直接注册了BLE监听器
- 每次调用都注册新监听器，但从未清除
- 多个监听器同时存在，拦截并消费了manifest数据
- 导致 `module-config.js` 的 `manifestCallback` 收不到数据

**解决方案**:
1. 移除 `gallery.js` 的临时监听器
2. 在 `bluetooth.js` 添加 `getGalleryList()` 方法
3. 使用 `galleryListCallback` 机制统一管理

**修改文件**:
- `utils/bluetooth.js` - 添加 `getGalleryList()` 和 `galleryListCallback`
- `pages/gallery/gallery.js` - 使用 `bluetooth.getGalleryList()`

---

### 问题2: 点击图片占位符后刷新列表失败

**现象**: 
- 点击图片占位符从设备获取图片
- 获取成功后，下拉刷新列表失败
- 模块配置页面也无法加载

**根因**:
- `gallery.js` 的 `fetchImageFromDevice()` 直接注册了BLE监听器
- 每次点击图片都注册新监听器，从未清除
- 监听器累加，干扰了所有后续的BLE通信

**解决方案**:
1. 在 `bluetooth.js` 添加 `getImageFromDevice()` 方法
2. 添加 `galleryImageCallback` 机制
3. 全局监听器识别 `image_data` 字段并分发
4. 重构 `fetchImageFromDevice()` 使用统一接口
5. 添加进度回调支持

**修改文件**:
- `utils/bluetooth.js` - 添加 `getImageFromDevice(filename, onProgress)`
- `pages/gallery/gallery.js` - 重构 `fetchImageFromDevice()`

---

### 问题3: 第二次扫描设备无法发现

**现象**: 
- 第一次扫描能发现17个设备，包括MiniEink
- 返回后第二次扫描只发现2-5个设备，MiniEink不出现
- 但点击历史设备仍能连接

**根因**:
- 微信小程序BLE扫描有多层缓存机制
- `stopBluetoothDevicesDiscovery()` 无法清除所有缓存
- 第二次扫描时，已缓存的设备不会重复回调

**解决方案**:
1. 每次扫描前调用 `wx.closeBluetoothAdapter()` 完全关闭
2. 等待100ms让系统释放资源
3. 重新初始化蓝牙适配器
4. 使用 `allowDuplicatesKey: true, interval: 0` 提高发现率
5. 优化超时定时器管理，防止堆积

**修改文件**:
- `utils/bluetooth.js` - `startScan()` 添加适配器重启逻辑（关闭再打开清除缓存）
- `pages/device-connect/device-connect.js` - 添加 `scanTimeout` 管理

---

### 问题4: 相册图片下载导致设备崩溃（Load access fault）

**现象**: 小程序点击相册图片占位符下载图片时，设备端重启，
日志停在 `Sending image data via set_status (auto-chunked)...`。

**根因**: `gallery_get` 先把 28,800 字节图片拼成 38,400 字符的 Base64 String，
再拼成完整响应 String（峰值约 3×38KB 临时内存），把 ESP32-C3 堆耗尽，
`set_status` 分块时分配 packet 失败 → 空指针 → Load access fault。

**解决方案**: 新增 `send_gallery_image_chunked()` 流式发送——边读文件边
Base64 编码，按 120 字符累积直接 notify 分块，全程不构建大 String
（峰值仅约几百字节）。块格式与 `set_status` 一致，前端无需改动。
BLE 通知做了节流与退避（`notify()` 失败延时重试、成功后 2ms 间隔），
避免连发 300+ 个通知把 NimBLE 队列塞满导致丢包（表现为进度卡在 30-40%
后超时）。小程序端 `getImageFromDevice` 超时同步放宽到 60 秒。

**修改文件**: `src/ble_config.cpp`、`utils/bluetooth.js`

---

### 问题5: 图片上传提速后丢块/花图（单槽命令队列）

**现象**:
- 提速版（0ms 连发）设备只收到 13104/28800 字节（正好 39 块），前端却全写"成功"
- 加上 20ms 限速 + 补发后，墨水屏显示完全错位的花图

**根因**:
- 设备端 `onWrite` 回调只把命令存入**单槽变量** `s_pending_cmd`，由主循环
  `ble_config_update()` 逐个取出处理；高频分块时新命令覆盖旧命令 → 静默丢块
- 前端写 API 只代表"写入链路成功"，不代表设备已处理（丢块无法感知）
- 修复 v2 的"按接收偏移追加"在补发与原始队列交错时错位写入 → 花图

**解决方案**:
1. 设备端：图片上传命令（start/chunk/progress/complete）在 **BLE 回调中直通处理**，
   绕过单槽队列；预分配解码缓冲区，去掉每块 String 拷贝与 malloc/free
2. 分块带 `index`，按 `index*chunk_size` 固定偏移落位，重复/乱序块直接忽略
   （无论补发怎么交错都不会写错位）
3. 新增 `gallery_upload_progress`：返回"从0起连续收到的字节数"（前缀），
   前端轮询进度，只有连续两次无进展才补发缺失后缀
4. 前端 `uploadComplete()` 等待设备真实保存结果，失败提示具体错误

**修改文件**: `src/ble_config.cpp`、`utils/bluetooth.js`、`pages/gallery/gallery.js`

---

## 功能特性

### 1. 设备端特性

#### 相册功能 (gallery.cpp)
- 图片存储：SPIFFS文件系统
- 支持格式：4色屏 2bit（200x200，10,000字节）；6色屏 4bit（240x240，28,800字节）
- 上传：336字节分块 + 索引落位，设备端 BLE 回调直通处理 + 进度校验补发，
  预期 2-3 秒（详见"BLE通信协议 → 图片上传"）
- 旋转：0°/90°/180°/270° 四个方向（**全局配置**，位于模块页“显示方向”，
  通过 `gallery_rotation` 键保存，设备状态含 `rotation` 字段）
  - 相册：显示时旋转帧缓冲（`rotate_image` / `rotate_image6`）
  - Lua 模块（倒计时等）：`display_prepare_canvas()` 统一 `Paint_SetRotate`，
    重绘（退出 BLE / 刷新显示）后整屏生效
- 循环播放：可配置间隔（1分钟~24小时）
- 空态提示：相册无图片时显示"请上传图片：长按上键等待蓝色指示灯亮，通过小程序
  '幻彩抽屉'连接设备上传图片。"（size 4 24x24 中文字库，UTF-8 安全自动换行居中，
  随全局显示方向旋转；有图后正常显示图片）
- 按键切换：KEY_DOWN 下一张 / KEY_UP 上一张（模块钩子 `subpage_next/subpage_prev`，
  按键唤醒跳过 setup，钩子内部懒初始化图片列表后直接切换）。
  `check_btn` 会补发一次短按事件（唤醒键在轮询前已松开时）：
  KEY_DOWN 短按 → 下一张并进入深度休眠；KEY_UP 短按 → 上一张并进入深度休眠；
  长按 KEY_DOWN（3秒）→ 只触发"切换下一个模块"；长按 KEY_UP → 开关 BLE，
  均不执行短按动作。休眠唤醒长按切模块后，等 KEY_DOWN 释放再进入深度休眠
  （`s_sleep_after_wake_switch`，避免按住时立即休眠导致低电平再次唤醒）
- 进入相册模块（上电 / 定时唤醒 / 从其他模块切换）：`gallery_setup` 显示
  "当前应显示的内容"——循环模式每次绘制下一张，固定模式显示已保存 `img_index`
  对应图片；按键唤醒不经 setup，由按键钩子直接切换
- 限制：仅MiniEink设备支持

**配置项** (`data/gallery.cfg`):
JSON 配置定义数组：`display_mode`（显示模式）、`cycle_interval`（循环间隔）。
显示方向不再出现在相册配置页，改由模块页全局设置。

#### 名言警句模块 (quotes.lua)
- 内置 431 条国内外名言警句（中国古代/唐诗宋词/近现代/外国哲理中文/英文原句），
  全部字符经 GB2312 字库映射校验（无缺字）
- 内存优化：数据用**扁平数组**（每条 "名言\t作者" 单字符串对象），避免 431 个
  嵌套小表占用大量 Lua 堆；脚本由设备端**流式加载**（`luaL_loadfile`，不再拼进
  C++ String），修复 ESP32-C3 上 "not enough memory" 问题
- 中文显示：GB2312 映射表（约29KB）在**开机时预加载**（`lua_hardware_preload_gb2312`），
  避免 BLE 会话中首次绘制中文时因堆不足加载失败导致文字全部显示为 `?`
  （加载失败会保持未加载状态，下次绘制自动重试）
- 布局：无标题/分隔线，正文直接用最大字号（size 4：中文 24x24，ASCII 17x24）
  自动换行、整块垂直居中 + 右下红色作者；中英文混排按显示宽度换行
  （英文尽量整词断行），超出行数自动省略
- 切换间隔：`interval` 配置（分钟），选项与相册循环间隔一致（1分钟~24小时，默认1小时）
- 显示顺序：`order` 配置（0=按顺序，1=随机，默认按顺序）
- 按键切换：KEY_DOWN 短按下一条 / KEY_UP 短按上一条（Lua `subpage_next/subpage_prev`
  钩子，首尾回绕；**连续按键可逐步切换**——当前索引经 `sys.set_state/get_state`
  存入 RTC 内存，深度休眠保持、掉电清零；切换后立即休眠，下次定时唤醒按槽位刷新）
- 轮换策略：按顺序模式按 `当前时刻/切换间隔` 取槽位确定条目（纯时间推导，
  深度休眠唤醒后稳定轮换，无需模块持久化状态）；随机模式以当前时刻为随机种子，
  每次唤醒/切换随机取一条
- 休眠定时唤醒：见"休眠管理 → 模块定时唤醒"（`interval` 分钟级）

#### 休眠管理 (sleep_manager.cpp)
- **统一休眠模型**：任何逻辑执行完立即进入深度休眠，只有 BLE 配置模式保持唤醒。
  - **电池保护**：每次开机（上电 / 按键 / 定时唤醒）`setup()` 先测电压
    （`battery.h` 的 `BATTERY_LOW_MV = 3100` mV）；低于阈值时不执行任何模块逻辑
    （不绘制、不进 BLE），直接 `enter_deep_sleep()`；保留按键 + 模块定时唤醒，
    电压恢复后再次开机自动继续正常运行。若由按键唤醒且按键仍按住，
    等释放后再休眠，避免 GPIO 低电平立即再次唤醒形成开机循环
  - 上电 / 定时唤醒：模块 `setup()` 绘制 → 立即 `enter_deep_sleep()`
  - 按键唤醒：跳过 setup，由 `check_btn` 判定 → 短按动作/切模块后休眠，
    长按 KEY_UP 进入 BLE 保持唤醒
  - BLE 开启后 **60 秒无连接**：自动停止广播并休眠（`BLE_NO_CONNECT_TIMEOUT_MS`，
    写死，不依赖配置；连接后取消计时，断开后仍走"会话结束立即休眠"）
  - BLE 会话结束（长按 KEY_UP 退出 / 小程序断开）：立即休眠，不重绘屏幕，
    新配置在下次唤醒的 `setup()` 中生效
- **BLE 省电优化**（A+B+D+E）：
  - **A. light sleep**：`platformio.ini` 的 `custom_sdkconfig` 开启
    `CONFIG_PM_ENABLE=y` + `CONFIG_FREERTOS_USE_TICKLESS_IDLE=y`，且必须同时开启
    **蓝牙控制器低功耗**：
    - `CONFIG_BT_CTRL_MODEM_SLEEP=y`（蓝牙 modem sleep，否则控制器以
      `ESP_BT_SLEEP_MODE_NONE` 初始化，使能时持有 `ESP_PM_NO_LIGHT_SLEEP` 锁，
      **直接禁止系统 light sleep**，实测仍 41mA 即此原因）
    - `CONFIG_BT_CTRL_LPCLK_SEL_MAIN_XTAL=y`（主晶振做低功耗时钟，C3 无外部 32k）
    - `CONFIG_BT_CTRL_MAIN_XTAL_PU_DURING_LIGHT_SLEEP=y`（light sleep 期间主晶振
      保持上电，否则 `lpclk_sel==MAIN_XTAL` 时 `no_light_sleep` 仍为 1）
    BLE 广播/空闲时系统可进入 light sleep（C3 支持 BT 唤醒 + BT 断电），广播平均
    电流从 ~41mA 降至数 mA 量级（主晶振保持上电有几百 µA 代价）。⚠️ 自定义 sdkconfig
    会触发一次 Arduino IDF 库全量重编（约 10-30 分钟，含组件下载，Windows 偶发组件
    目录被占用报 WinError 32/145，清理对应 managed_components 子目录重试即可），
    成功后缓存（`sdkconfig.defaults` 写入哈希），之后为增量构建
  - **BLE 模式附加省电**（实测 41→20mA 后再压）：
    - 进入 BLE 前 `epdFinishPowerOff()` + `epdClearRefreshPending()`（仅 INK6）：
      按键唤醒进 BLE 时 6 色面板仍处于 init 后未断电状态，驱动 IC 持续耗电
    - 蓝色指示灯改 LEDC 低占空比 PWM（1kHz、8bit、5%），常亮约 2~8mA → ~0.2mA
  - **B. 广播间隔 100~200ms**：`NimBLEAdvertising::setMinInterval(160)/setMaxInterval(320)`
    （单位 0.625ms），替代默认约 40ms 快速广播
  - **D. TX 功率 0dBm**：`NimBLEDevice::setPower(0)`（近距离连接足够）
  - **E. CPU 80MHz**：进入 BLE 时 `setCpuFrequencyMhz(80)`，`ble_config_stop()` 恢复 160
  - 依赖的平台补丁（pioarduino，机器级）：
    - `component_manager.py`：lib_ignore 剪组件时应用 BT/BLE 保护
    - `espidf.py`：`get_lib_ignore_components` 从 `platformio.ini`（UTF-8）读取
      `lib_deps` 判断 NimBLE 依赖，避免自定义 sdkconfig 重建库时剪掉 bt 组件
    - `src/log_printf_wrap.cpp`：补 `__wrap_log_printf`（core 3.3.8 移除该符号，
      pioarduino 链接脚本仍保留 `-Wl,--wrap=log_printf`）
  - 原 `-DCONFIG_BT_ENABLED=0 -DCONFIG_BLUEDROID_ENABLED=0` 已移除（与 sdkconfig
    冲突，且会导致库构建时自带 BLE 库误判走 Bluedroid 分支）
- 已移除：空闲超时（`sleep_sec` 仅存档，不再控制休眠）、模块常驻 `loop`、
  Lua `sys.wake_source()`（模块 setup 一律绘制，按键唤醒由系统层跳过）
- **模块定时唤醒**：`module_descriptor_t` 的 `wake_interval` 钩子返回秒（0=不启用），
  `enter_deep_sleep()` 按当前模块配置 `esp_sleep_enable_timer_wakeup`
  ⚠️ `wake_interval` 可能被 30 秒断电快路径在模块 `setup` **之前**查询，
  实现必须独立于模块运行时状态（如直接读 NVS 配置，参考相册/Lua 的实现）
  - 相册：循环播放模式下按 `cycle_interval`（分钟）定时唤醒切换
  - Lua 模块：通用实现（`dynamic_lua_wake_interval`）统一读取模块配置 `interval`
    （**分钟**，1~1440，名言/倒计时通用；NVS 键名最长15字符，故配置键须 ≤15），
    `refresh`（小时）仅作旧版倒计时配置兼容（`interval` 未保存时回退），
    定时唤醒后 `setup()` 重绘并立即休眠；异步刷屏期间 MCU 直接休眠，
    面板刷新结束后由定时唤醒完成断电，再按模块周期继续休眠
- **系统级异步刷屏（4色 / 6色 / 黑白屏统一）**：见下方“异步刷屏调度层”
  （`include/epd_async.h`）。面板刷新由控制器内部定时序，`eink_display_frame()`
  发完刷新命令立即返回并置 RTC 标志 `s_refresh_pending`，不依赖任何模块特判。
  - **BUSY 等待省电**：`epdWaitBusy` 轮询间隔从 `delay(1)` 改为 `delay(20)`——
    tickless idle 入睡阈值为 8ms（`FREERTOS_IDLE_TIME_BEFORE_SLEEP=8` @ 1000Hz），
    1ms 轮询让 CPU 永远睡不进 light sleep，等待面板 BUSY（如 30 秒断电快路径最多
    等 40 秒）时 CPU 全程活跃约 15mA；20ms 轮询可进入 light sleep，
    该阶段电流从 ~18mA 降至面板自身的 3~5mA。主循环 `delay(10)` 同步改为 `delay(20)`

**时间与时区**：
- 时间戳（UTC）由 BLE `sync_time` 同步，`TimeCalibration` 存 RTC 内存（深睡保持）
- 时区偏移同时存 RTC 内存与 NVS（`system/tz_offset`），掉电后从 NVS 恢复；
  `sync_time` 命令未携带 `timezone` 字段时不会清零已有时区（避免倒计时差8小时）

### 2. 小程序特性

#### 相册管理 (gallery页面)
- ✅ 图片上传：选择相册/拍照 → 编辑页处理 → 上传；按设备 `ink` 自动转换
  - 编辑页无确定/取消按钮，主按钮为"预览上传"
  - 预览弹窗：抖动算法选择（Floyd/Atkinson/Burkes/Stucki/无抖动）+ 亮度/对比度/冷暖
    滑块（实时预览）+ 右上角"上传"按钮
  - 转换管道：用户调节 → 肤色暖化(warmEnhance) → 色相分类 → 色相门控抖动 → 打包
    （肤色暖化仅对暖色皮肤提红压蓝，避免面部偏冷；色相门控防止误差扩散串色）
  - 上传等待设备真实保存结果，失败显示设备返回的错误（如 Save failed）
- ✅ 图片文件名：`img_年月日时分秒.img`（如 img_20260812114147.img），非毫秒时间戳
- ✅ 图片预览：点击占位符从设备获取，支持进度显示
- ✅ 批量删除：长按进入批量模式
- ✅ 显示到墨水屏：一键推送显示
- ✅ 本地缓存：已获取的图片缓存在本地存储
  - 缓存键 `gallery_image_cache_v2`（v1 按旧名义色板生成，已作废清理）
  - 6色缩略图解码色板与编辑页校准色板一致，避免列表蓝色过艳
- ✅ 下拉刷新：手动刷新列表
- ⚠️ 仅MiniEink设备可用，其他设备会提示

#### 模块管理 (modules页面)
- 模块列表：显示已安装模块
- **电量显示**：顶部设备名右侧显示 🔋 百分比（<20% 变红），前端由 `battery_mv` 换算
- 开关控制：启用/禁用模块
- 配置入口：点击进入详细配置
- 删除模块：卸载模块
- **亮度设置**：仅非MiniEink设备显示（墨水屏无背光）
- **休眠时间**：前端已按设备型号隐藏（`!isMiniEink`），MiniEink 不再展示；
  Bottle 等设备仍保留并使用该配置

#### 模块市场 (market页面)
- 模块列表：云函数 `getModules` 拉取，支持分类/搜索/下拉刷新
- ✅ **按硬件型号过滤**：模块 `supportedModels` 数组（如 `bottlev1`/`bottlev4`，
  未声明或含 `通用` 表示所有设备可见）；连接设备后前端用 `deviceStatus.model`
  （设备 `get_status` 返回的 `DEVICE_MODEL`，如 `Bottle-V1`/`Eink-V1`）归一化
  （小写去分隔符）匹配过滤；未连接/未知型号时显示全部
- 过滤后无可用模块时显示"当前设备暂无可用模块"
- 下载：按 `deviceModel` 传给 `getModuleDetail`，优先型号专用代码，降级通用代码

#### 设备连接 (device-connect页面)
- BLE扫描：自动过滤 BottleLED/MiniEink 设备
- 扫描超时：15秒
- 历史设备：保存已连接设备，快速重连
- 自动清理：扫描完成后清除蓝牙缓存

---

## 常见陷阱与最佳实践

### 1. ⚠️ BLE监听器泄漏

**问题**: 微信小程序的 `wx.onBLECharacteristicValueChange()` 是**累加式注册**，每次调用都添加新监听器。

**解决**: 使用 `bluetooth.js` 的全局单例监听器 + callback机制（见"统一BLE架构"章节）。

**排查方法**:
```bash
# 搜索页面中的监听器注册
grep -rn "onBLECharacteristicValueChange" pages/ --include="*.js"
# 应该返回空，所有监听器都在bluetooth.js中
```

---

### 2. ⚠️ 设备端固件上传限制

**重要**: 根据 `AGENT_HANDOFF.md`，**不要上传固件**到设备，只编译！

```bash
# ✅ 正确 - 仅编译
cd /d/Projects/Eink
/d/.platformio/penv/Scripts/platformio.exe run

# ❌ 错误 - 不要上传
platformio.exe run --target upload
```

---

### 3. ⚠️ 分块数据验证

**问题**: 分块数据可能混入非目标数据。

**示例**: 等待manifest分块时，可能收到status更新的分块。

**解决**: 合并后验证数据结构
```javascript
const manifest = JSON.parse(fullData);
if (!manifest.id || !manifest.configs) {
  // 不是manifest，重置chunks继续等待
  chunks = {};
  return;
}
```

---

### 4. ⚠️ TabBar页面生命周期

**问题**: TabBar页面不会触发 `onUnload`，只触发 `onShow`/`onHide`。

**影响**: 页面级的临时资源无法在 `onUnload` 中清理。

**解决**: 
- 不要在TabBar页面注册临时BLE监听器
- 使用全局单例 + callback机制
- 在 `onHide` 中清理临时状态

---

### 5. ⚠️ 进度条动画重绘

**问题**: 频繁调用 `wx.showLoading()` 会导致loading动画重新开始。

**解决**: 降低更新频率（如：只在进度变化≥5%时更新）。

---

### 6. ⚠️ BLE 单槽命令队列（设备端）

**问题**: 设备端 `onWrite` 只把命令存入单个 `s_pending_cmd` 变量，
主循环逐个处理；高频命令（如图片分块）会覆盖未处理的旧命令 → 静默丢块，
且前端写 API 无法感知（写"成功"≠设备已处理）。

**解决**:
- 高频命令（图片上传）在 BLE 回调中直通处理，不经过单槽队列
- 需要重传语义的命令带 `index`，设备按固定偏移落位、重复块忽略
- 前端以设备实际接收进度为准（`gallery_upload_progress`），不要信任写返回值

---

## 编译与调试

### 设备端编译

**环境**:
- PlatformIO: `D:\.platformio\penv\Scripts\platformio.exe`
- 工作目录: `d:\Projects\Eink`

**命令**:
```bash
cd /d/Projects/Eink
/d/.platformio/penv/Scripts/platformio.exe run
```

**Flash 分区表** (`partitions.csv`，4MB Flash):
- `nvs`(20KB) + `otadata`(8KB) + `app0`(992KB, ota_0) + `modules`(2.96875MB, SPIFFS)
- 已移除 `app1`/OTA 分区（固件 OTA 逻辑已全部注释），把空余空间全部并入 `modules` 分区
- `app0` 按当前固件体积预留约 10% 余量（`0xF8000`=1015808B，当前 firmware.bin 921216B）；
  后续固件若显著增大需同步复核 `partitions.csv`
- ⚠️ 刷入新分区表后 SPIFFS 容量变化会触发格式化，需重新 `uploadfs` 上传 `data/` 目录
  （Lua 模块、字体、配置），否则设备上旧数据失效

**常见错误**:
1. **undefined reference to 'enter_deep_sleep()'**
   - 原因: 缺少头文件
   - 修复: 添加 `#include "sleep_manager.h"`

2. **timerBegin参数错误**
   - 原因: 新版API已变更
   - 新API: `timerBegin(freq)`, `timerAttachInterrupt()`, `timerAlarm()`

---

### 小程序调试

**工具**: 微信开发者工具

**注意事项**:
1. **BLE必须真机调试**，开发者工具无法模拟
2. 打开"调试基础库"选项
3. 使用 `console.log()` 输出到Console

**关键调试位置**:
- `bluetooth.js::setupGlobalListener()` - BLE数据接收
- `bluetooth.js::manifestCallback` - 模块配置响应
- `bluetooth.js::galleryListCallback` - 图片列表响应
- `bluetooth.js::galleryImageCallback` - 单张图片响应
- `bluetooth.js::uploadResultCallback` - 图片上传进度/保存结果回执
- `bluetooth.js::uploadComplete()` - 等待设备端真实保存结果
- `bluetooth.js::getUploadProgress()` - 查询上传接收进度（丢包补齐）

---

## 文档维护指南

### Claude Code 文件写入最佳实践

在使用Claude Code进行文档编写时，遇到过文件写入工具的问题和解决方案：

#### 问题现象
使用 `Write` 工具创建大型文档时出现错误：
```
InputValidationError: Write was called with input that could not be parsed as JSON.
```

#### 根本原因
- **Write工具限制**: 单次写入内容不能超过约4000个token或8000字符
- **路径格式**: Windows路径中的反斜杠需要正确转义
- **大文档**: 超过150行或8000字符的内容会导致API截断

#### 正确的解决方案

**方案1: PowerShell分块写入（推荐用于大文档）**
```powershell
# 第一步：创建文件头
@'
# 文档标题
第一部分内容...
'@ | Out-File -FilePath "path/to/file.md" -Encoding utf8 -NoNewline

# 第二步：追加内容
@'
第二部分内容...
'@ | Add-Content -Path "path/to/file.md" -Encoding utf8 -NoNewline

# 第三步：继续追加
@'
第三部分内容...
'@ | Add-Content -Path "path/to/file.md" -Encoding utf8 -NoNewline
```

**方案2: Bash + heredoc（适用于中等大小文档）**
```bash
cat > /path/to/file.md << 'EOF'
文档内容...
EOF
```

**方案3: Write工具（仅适用于小文件 <150行）**
```
只用于创建小文件或代码文件，不适合大型文档。
```

#### 最佳实践总结

**✅ 推荐做法**:
1. **大型文档（>500行）**: 使用PowerShell分块写入
   - 第一次用 `Out-File` 创建
   - 后续用 `Add-Content` 追加
   - 每块控制在200-300行以内
   - 使用 `-NoNewline` 避免额外换行

2. **中型文档（200-500行）**: 使用Bash heredoc
   - 注意heredoc结束符必须顶格（`EOF`前无空格）
   - 使用单引号 `'EOF'` 避免变量展开

3. **小型文件（<150行）**: 使用Write工具
   - 代码文件
   - 配置文件
   - 短文档

4. **路径处理**:
   - Windows路径优先使用正斜杠: `d:/Projects/Eink/file.md`
   - 或者在Bash中使用: `/d/Projects/Eink/file.md`
   - 避免反斜杠转义问题

**❌ 避免做法**:
- 不要用Write工具一次性写入超过150行的文档
- 不要在PowerShell heredoc中使用复杂的引号嵌套
- 不要在Bash heredoc结束符前添加空格或制表符

#### 实际案例

本项目中创建 `LUA_SCRIPT_GUIDE.md` (1010行) 的成功方案：

```powershell
# 步骤1: 创建前200行
@'
# Lua 模块开发指南
...前200行内容...
'@ | Out-File -FilePath "d:\Projects\Eink\docs\LUA_SCRIPT_GUIDE.md" -Encoding utf8 -NoNewline

# 步骤2: 追加配置系统和API部分（约300行）
@'
### 配置系统
...中间内容...
'@ | Add-Content -Path "d:\Projects\Eink\docs\LUA_SCRIPT_GUIDE.md" -Encoding utf8 -NoNewline

# 步骤3: 追加示例和参考（约500行）
@'
## 示例模块
...后续内容...
'@ | Add-Content -Path "d:\Projects\Eink\docs\LUA_SCRIPT_GUIDE.md" -Encoding utf8 -NoNewline
```

#### 验证方法

创建文档后验证：
```bash
# 检查行数
wc -l /d/Projects/Eink/docs/LUA_SCRIPT_GUIDE.md

# 检查开头
head -20 /d/Projects/Eink/docs/LUA_SCRIPT_GUIDE.md

# 检查结尾
tail -20 /d/Projects/Eink/docs/LUA_SCRIPT_GUIDE.md

# 搜索关键内容验证完整性
grep -c "## " /d/Projects/Eink/docs/LUA_SCRIPT_GUIDE.md
```

---

## 测试流程

### 完整功能测试

#### 1. 设备连接测试
- [ ] 打开小程序
- [ ] 进入设备连接页面
- [ ] 点击"开始扫描"
- [ ] 应该能发现MiniEink设备（15秒内）
- [ ] 返回，再次扫描 - 应该还能发现（验证缓存清除）
- [ ] 点击设备连接
- [ ] 连接成功，跳转到模块页面

#### 2. 模块管理测试
- [ ] 连接MiniEink设备
- [ ] 模块页面**不应显示亮度设置**（墨水屏无背光）
- [ ] MiniEink 模块页**不应显示休眠时间**（Bottle 设备保留）
- [ ] 点击任意模块进入配置页面
- [ ] 配置页面应该正常加载（不转圈）

#### 3. 相册功能测试
- [ ] 点击底部"相册"图标
- [ ] 如果未连接设备，应该显示空状态
- [ ] 如果连接非MiniEink设备，应该提示"功能不可用"并返回
- [ ] 连接MiniEink设备后，应该加载图片列表
- [ ] **上传图片**:
  - [ ] 点击"上传图片"按钮
  - [ ] 选择一张照片
  - [ ] 应该显示 "上传中 X%" 进度
  - [ ] 上传成功后，列表自动刷新
- [ ] **点击占位符**:
  - [ ] 点击未缓存的图片占位符
  - [ ] 应该显示 "加载中 X%" 进度
  - [ ] 加载完成后预览图片
- [ ] **下拉刷新**:
  - [ ] 下拉列表
  - [ ] 应该刷新成功（不会失败）
- [ ] **切换页面**:
  - [ ] 切换到模块页
  - [ ] 再切换回相册页
  - [ ] **不应该自动刷新**（已有数据）

#### 4. 压力测试
- [ ] 快速切换TabBar页面10次
- [ ] 不应该出现加载失败
- [ ] 点击相册模块配置10次
- [ ] 每次都应该正常加载
- [ ] 上传多张图片
- [ ] 每次都应该成功刷新列表

---

## 项目依赖

### 设备端 (platformio.ini)
```ini
[env:pico32]
platform = espressif32
board = adafruit_qtpy_esp32c3
framework = arduino
lib_deps = 
    FastLED @ 3.10.3
    arduinoFFT @ 2.0.4
    NimBLE-Arduino @ 2.5.0
    Lua @ 5.4.7
```

### 小程序 (package.json)
```json
{
  "dependencies": {
    "regenerator-runtime": "^0.13.9"
  }
}
```

**云开发环境**: cloud1-d3gxxnyov88776090

---

## 待办事项

### 已完成 ✅
- [x] 修复BLE监听器泄漏问题
- [x] 修复设备扫描缓存问题
- [x] 统一BLE数据接收架构
- [x] 添加图片旋转功能
- [x] 优化相册页面刷新逻辑
- [x] 统一进度条样式
- [x] MiniEink设备UI优化
- [x] 市场模块按设备型号过滤（supportedModels）
- [x] 创建完整项目交接文档
- [x] 创建Lua开发规范文档

### 待实现 🔲
- [ ] 考虑添加设备端广播间隔配置（提高扫描发现率）
- [ ] 优化分块传输大小（当前200字节）
- [ ] 添加更多设备类型支持
- [ ] 完善错误处理和用户提示
- [ ] 相册图片压缩优化
- [ ] 添加图片轮播预览功能
- [ ] Lua模块市场功能

---

## 联系信息

- **用户**: jeff
- **Git用户**: jeffreyer
- **设备端项目**: d:\Projects\Eink
- **小程序项目**: d:\Projects\jeff\WeChatProjects\pix

---

## 附录：关键代码片段

### A. 设备端分块发送

```cpp
// ble_config.cpp
void set_status(const String &status) {
    const size_t CHUNK_SIZE = 200;
    if (status.length() > CHUNK_SIZE) {
        size_t total = (status.length() + CHUNK_SIZE - 1) / CHUNK_SIZE;
        for (size_t i = 0; i < total; i++) {
            StaticJsonDocument<256> chunk_doc;
            chunk_doc["chunk"] = i;
            chunk_doc["total"] = total;
            chunk_doc["data"] = status.substring(
                i * CHUNK_SIZE, 
                min((i + 1) * CHUNK_SIZE, status.length())
            );
            String chunk_str;
            serializeJson(chunk_doc, chunk_str);
            s_status_char->setValue(chunk_str.c_str());
            s_status_char->notify();
            delay(30);  // 给小程序处理时间
        }
    } else {
        s_status_char->setValue(status.c_str());
        s_status_char->notify();
    }
}
```

### B. 小程序分块接收

```javascript
// bluetooth.js
this.galleryListCallback = (data) => {
  if (data.chunk !== undefined && data.total !== undefined) {
    chunks[data.chunk] = data.data;
    
    if (Object.keys(chunks).length === data.total) {
      let fullData = '';
      for (let i = 0; i < data.total; i++) {
        fullData += chunks[i];
      }
      
      const result = JSON.parse(fullData);
      
      // 验证数据结构
      if (!result.images) {
        chunks = {};  // 不是期望的数据，重置
        return;
      }
      
      resolve({ success: true, images: result.images });
    }
  } else if (data.images) {
    // 非分块数据，直接返回
    resolve({ success: true, images: data.images });
  }
};
```

### C. 图片旋转算法

```cpp
// gallery.cpp
void rotate_image(uint8_t* image, int width, int height, int degrees) {
    uint8_t* temp = (uint8_t*)malloc(total_bytes);
    memcpy(temp, image, total_bytes);
    memset(image, 0, total_bytes);
    
    if (degrees == 90) {
        // 90度顺时针: (x,y) -> (height-1-y, x)
        for (int y = 0; y < height; y++) {
            for (int x = 0; x < width; x++) {
                int new_x = height - 1 - y;
                int new_y = x;
                // 复制像素位...
            }
        }
    }
    // 180度、270度类似...
    
    free(temp);
}
```

---

## Lua 模块开发

### 开发文档
**完整开发规范**: `d:\Projects\Eink\docs\LUA_SCRIPT_GUIDE.md`

### 快速参考

#### 关键特性
- **元数据格式**: `-- @key: value` （单行注释+冒号，与Bottle一致）
- **配置文件**: `module-id.cfg` （JSON数组格式）
- **显示**: 4色墨水屏（黑=0, 白=1, 黄=2, 红=3）
- **刷新**: 约12秒，建议间隔≥30秒
- **屏幕**: 200×200像素

#### API概览
```lua
-- 显示
display.clear()
display.pixel(x, y, color)
display.text(x, y, str, size)
display.show()

-- 时间
local h, m, s = time.get()
time.delay(ms)

-- 配置
local value = CONFIG.key or default
```

#### 重要规则
1. 文件名和 `@id` 使用连字符 `-`，不用下划线 `_`
2. `@description` 不超过128字节（约42个中文字符）
3. 减少刷新频率，避免频繁调用 `display.show()`

#### 项目继承关系
**MiniEink的Lua框架继承自Bottle项目**（`D:\Projects\Bottle`）
- 元数据格式、配置系统、标准库完全一致
- 如需修改底层Lua解析逻辑，参考Bottle项目源码
- 日常开发无需了解Bottle，参考本项目文档即可

---

**文档版本**: v2.1  
**维护者**: jeffreyer

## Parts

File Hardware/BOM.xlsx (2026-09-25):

Comment | Description | Designator | Footprint | Quantity
ANT5520 | 2.4G贴片天线 CrossAir CA-C03 | AE1 | ANT_5520 | 1
1uF |  | C1, C2, C3, C5, C7, C12, C14, C15, C16, C17, C18, C20, C22, C24, C32 | C0402 | 15
10nF |  | C4 | C0402 | 1
4.7uF |  | C6, C11 | C0402 | 2
10uF | [NoValue], 容值:10uF;精度:±10%;额定电压:25V;材质(温度系数):X5R; | C8, C25, C28, C29 | C0402 | 4
100nF | [NoValue], 容值:100nF;精度:±10%;额定电压:50V;材质(温度系数):X7R; | C9, C10, C13, C19, C21, C30, C31 | C0402 | 7
47uF | 容值:47uF;精度:±10%;额定电压:10V;等效串联电阻:2.4Ω@100kHz; | C23 | C0603 | 1
15pF |  | C26, C27 | C0402 | 2
MBR0530 |  | D1, D2, D3 | SOD-123_L2.8-W1.8-LS3.7-RD | 3
B5819WS | 二极管配置:独立式;正向压降(Vf):600mV@1.0A;直流反向耐压(Vr):40V;整流电流:1A; | D5 | SOD-323_L1.7-W1.3-LS2.5-FD | 1
ESP32-C3FH4 |  | ESP1 | QFN-32_L5.0-W5.0-P0.50-TL-EP3.7 | 1
2nH |  | L1 | C0402 | 1
47uH |  | L2 | L_L3_W3 | 1
24nH |  | L3 | C0402 | 1
3nH | Inductor | L4 | C0402 | 1
LED-0402-R |  | LED1 | C0402 | 1
LED-0402-B |  | LED2 | C0402 | 1
FPC 0.5MM 24P Pull type H2.0mm Pick up |  | P1 | FPC-SMD_24P-L17.5-W5.4-P0.50 | 1
CJ3400 | 类型:N沟道;漏源电压(Vdss):30V;连续漏极电流(Id):5.8A;功率(Pd):350mW;导通电阻(RDS(on)@Vgs,Id):35mΩ@10V,5.8A;阈值电压(Vgs(th)@Id):1.4V@250uA; | Q1 | SOT-23_L2.9-W1.3-P1.90-LS2.4-BR | 1
AO3401A | 类型:P沟道;漏源电压(Vdss):30V;连续漏极电流(Id):4.2A;功率(Pd):350mW;导通电阻(RDS(on)@Vgs,Id):65mΩ@10V,4.2A; | Q2 | SOT-23-3_L2.9-W1.6-P1.90-LS2.8-BR_1 | 1
10K | [NoValue], 电阻类型:厚膜电阻;阻值:10kΩ;精度:±1%;功率:125mW; | R1, R4, R5, R7, R10, R15, R16 | R0402 | 7
3M | 电阻类型:厚膜电阻;阻值:10kΩ;精度:±1%;功率:125mW; | R2, R3 | R0402 | 2
2.2R |  | R6 | R0402 | 1
1kΩ | 电阻类型:厚膜电阻;阻值:1kΩ;精度:±1%;功率:100mW;工作电压:75V;温度系数:±100ppm/℃; | R8, R17 | R0402 | 2
5.1k |  | R9, R11, R14 | R0402 | 3
0r | 阻值:0Ω;精度:±1%;功率:62.5mW;温度系数:±800ppm/℃;电阻类型:厚膜电阻; | R12, R13, R18 | R0402 | 3
TS24CA 250gf 013 | 电路结构:单刀单掷;按钮形状:矩形按钮;作用力:250gf;安装方式:卧贴;开关长度:4.55mm;开关宽度:1.8mm;开关高度:3.5mm;带支架:不带;触点电流:50mA;额定电压(AC):-;额定电压(DC):12V;额定功率:0.6W;绝缘电阻:100MΩ;带灯:无;机械寿命:3万次; | SW1, SW2 | SW-SMD_L4.7-W3.5-P3.35-EH | 2
TP4067-4.35V |  | U1 | SOT-23-5_L3.0-W1.7-P0.95-LS2.8-BL | 1
RT9080-33GJ5 |  | U2 | SOT-23-5_L3.0-W1.7-P0.95-LS2.8-BL | 1
TYPEC | 连接器类型:Type-C;标准:USB 3.1;公母:母;端口数量:1;触点数量:16P;安装方式:沉板;额定电流 - 电源:5A;工作温度范围:-45℃~+85℃;焊接温度(最大值):260℃; | USB1 | USB-C-SMD_TYPEC-302-BRP16SC16 | 1
40MHz |  | X1 | CRYSTAL-SMD_4P-L2.5-W2.0-BL | 1
电池 | 店铺利赛奥电池新能源，跟客服沟通购买203240锂电池 |  |  | 1
屏幕 | 1.54寸24pin 6色4色黑白墨水屏

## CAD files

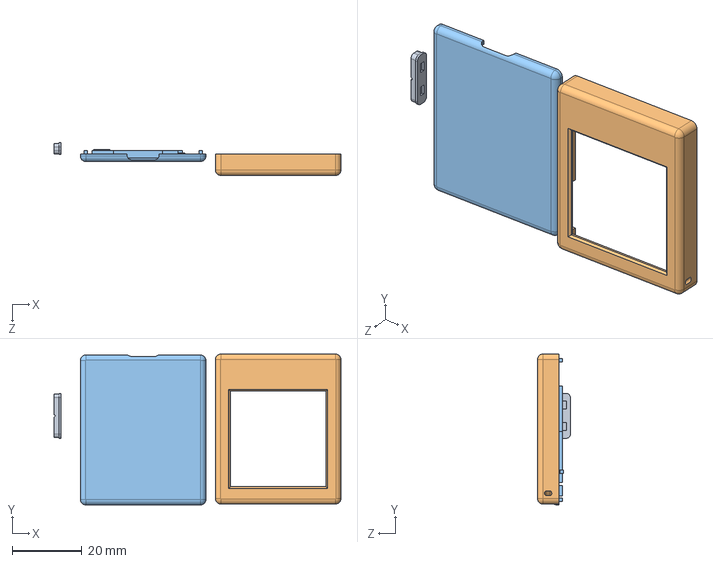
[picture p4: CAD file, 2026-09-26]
Hardware/3D外壳/墨水屏外壳.STEP
82.3 x 43.3 x 9.40 mm

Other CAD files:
Hardware/3D外壳/墨水屏外壳.3mf

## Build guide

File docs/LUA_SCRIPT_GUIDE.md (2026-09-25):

# Lua 模块开发指南

本文档为 AI 助手和开发者提供快速开发 Lua 模块的完整指南。

## 目录
- [硬件环境](#硬件环境)
- [文件结构](#文件结构)
- [核心 API](#核心-api)
- [模块开发模式](#模块开发模式)
- [常见问题](#常见问题)
- [最佳实践](#最佳实践)

---

## 硬件环境

### 墨水屏显示
- **设备型号**: MiniEink (基于 ESP32-C3)
- **屏幕尺寸**: 4色屏 200×200；6色屏（`INK6` 宏）240×240；黑白屏（`INK_BW` 宏）200×200
- **全局变量**: `WIDTH` 和 `HEIGHT` 由设备端注册，按固件编译模式自动为 200 或 240
- **坐标系**: 左上角为 (0, 0)，右下角为 (WIDTH-1, HEIGHT-1)
- **显示模式**: 4色显示（黑、白、黄、红）；6色显示（黑、白、黄、红、蓝、绿）；
  黑白屏为单色，颜色 2（黄）自动转为浅灰抖动、3/4/5 转为黑色，脚本无需改写
- **中文字库**: 设备内置全量 GB2312 点阵字库（16x16 / 24x24），`display.text`
  支持 UTF-8 中文（见“中文字库”一节）
- **刷新特性**: 
  - 刷新时间：4色屏约12秒；6色屏约30-40秒
  - 建议刷新间隔：≥30秒

---

## 文件结构

### 模块文件命名
```
module-id.lua           # 主脚本文件
module-id.cfg          # 配置文件（可选，JSON格式）
```

**命名规则**:
- 使用**连字符** (`-`)，不用下划线
- ✅ 正确：`clock-simple.lua`, `weather-mini.lua`
- ❌ 错误：`clock_simple.lua`, `weather_mini.lua`

### 必需的文件头元数据
```lua
-- @name: 时钟显示
-- @version: 1.0.0
-- @author: Your Name
-- @description: 在墨水屏上显示大字时钟
-- @id: clock-simple
```

**重要**: 
- 使用 `-- @key: value` 格式（单行注释+冒号+空格）
- `@id` 和文件名必须一致，都使用连字符
- `@description` 必须控制在 128 字节以内
- 中文字符约占 3 字节，建议不超过 42 个中文字符

### 脚本结构模板

```lua
-- @name: 时钟显示
-- @version: 1.0.0
-- @author: Your Name
-- @description: 在墨水屏上显示大字时钟
-- @id: clock-simple

function setup()
    print("模块初始化")
    display.clear()
    display.text(50, 90, "Hello", 3)
    display.show()
end

function unload()
    print("模块卸载")
    display.clear()
    display.show()
end
```

### 标准三函数结构

#### `setup()`
- 模块加载时调用一次，**负责绘制当前应显示的内容**
- 在 `setup()` 中读取配置并绘制（上电 / 定时唤醒 / 切换模块 / 刷新显示 都会调用）
- 必需函数

#### `loop()`
- **当前固件不再调用 `loop()`**（统一休眠模型：任何逻辑执行完立即休眠）
- 周期刷新请使用"深度休眠定时唤醒"（见下文），无需也不应编写 `loop()`

#### `unload()`
- 模块卸载时调用
- 用于清理资源、保存状态
- 可选函数

### 配置系统

#### 配置文件格式

创建 `[module-id].cfg`（JSON 数组格式）：

```json
[
  {
    "key": "time_format",
    "type": "select",
    "label": "时间格式",
    "options": [
      {"label": "24小时制", "value": "24h"},
      {"label": "12小时制", "value": "12h"}
    ],
    "default": "24h",
    "desc": "选择时间显示格式"
  },
  {
    "key": "interval",
    "type": "slider",
    "label": "刷新间隔",
    "min": 1,
    "max": 1440,
    "step": 1,
    "default": 60,
    "desc": "屏幕刷新间隔（分钟）"
  },
  {
    "key": "show_seconds",
    "type": "switch",
    "label": "显示秒数",
    "default": false,
    "desc": "是否显示秒数"
  },
  {
    "key": "message",
    "type": "text",
    "label": "显示消息",
    "default": "Hello",
    "maxlength": 20,
    "desc": "自定义显示文本"
  }
]
```

#### 配置类型

| 类型 | 说明 | 必需字段 |
|---|---|---|
| `select` | 下拉选择 | `options` (label, value) |
| `slider` | 滑动条 | `min`, `max`, `step` |
| `switch` | 开关 | - |
| `text` | 文本输入 | `maxlength` (可选) |
| `color` | 颜色选择器 | - |

#### 读取配置

配置通过全局 `CONFIG` 表访问：

```lua
-- 读取配置（提供默认值）
local format = CONFIG.time_format or "24h"
local interval = CONFIG.interval or 60
local message = CONFIG.message or "Hello"

-- 正确处理布尔值
local show_seconds = false
if CONFIG.show_seconds ~= nil then
    show_seconds = CONFIG.show_seconds
end
```

#### 配置变更自动生效

小程序端修改配置并写入 NVS 后，配置在**下次唤醒的 `setup()`** 中生效
（BLE 会话结束即休眠，不重绘；小程序"刷新显示"命令会立即重载模块）。
`setup()` 中重新注入的 `CONFIG` 表即包含最新配置值。因此：

- 在 `setup()` 中读取配置并绘制，无需自己监听配置变化；
- 每次 `setup()` 都会重新注入 `CONFIG`，模块状态随之重新初始化。

#### 深度休眠定时唤醒

设备**任何逻辑执行完立即进入深度休眠**（仅 BLE 配置模式保持唤醒）。Lua 模块
在配置中声明唤醒周期后，设备按周期定时唤醒并重新执行 `setup()` 完成重绘：

| 配置键 | 单位 | 说明 |
|---|---|---|
| `interval` | 分钟（1~1440） | **统一唤醒键**，所有 Lua 模块通用（名言/倒计时等） |
| `refresh` | 小时 | 仅旧版倒计时配置兼容（`interval` 未保存时回退，新模块不要使用） |

- 两键均在模块自己的 NVS 命名空间读取，与 `CONFIG` 表同源，只需在 `.cfg` 里
  定义 `interval`（键名 ≤15 字符），无需 C 端改动；
- 按键唤醒由系统层处理（跳过 setup，直接执行按键动作），模块**无需**也不应
  判断唤醒源；`setup()` 一律绘制当前应显示的内容；
- `setup()` 绘制完成后，系统会立即再次进入深度休眠。

#### 按键钩子（可选）

模块可在脚本顶层定义以下函数，注册 KEY_UP/KEY_DOWN 短按行为：

```lua
-- KEY_DOWN 短按：显示下一条
function subpage_next()
    draw_entry(next_index)
end

-- KEY_UP 短按：显示上一条
function subpage_prev()
    draw_entry(prev_index)
end
```

- 短按触发（含深度休眠按键唤醒场景），钩子内应自行调用 `display.show()`；
- 按键唤醒时系统**跳过 `setup()` 绘制**，但调用钩子前会自动**只加载脚本**
  （不执行 `setup()`），因此钩子可直接使用顶层数据表和辅助函数；
- 钩子执行完成后系统统一进入深度休眠（BLE 模式除外）。

---

## 核心 API

### 1. display - 显示控制

#### display.clear()
清空显示缓冲区（全白）。

```lua
display.clear()
```

#### display.pixel(x, y, color)
设置单个像素。

```lua
display.pixel(100, 100, 0)  -- 设置 (100, 100) 为黑色
display.pixel(50, 50, 1)    -- 设置 (50, 50) 为白色
display.pixel(20, 20, 2)    -- 设置 (20, 20) 为黄色
display.pixel(10, 10, 3)    -- 设置 (10, 10) 为红色
```

**参数**:
- `x`: 横坐标 (0-199)
- `y`: 纵坐标 (0-199)  
- `color`: 0=黑色, 1=白色, 2=黄色, 3=红色, 4=蓝色, 5=绿色（4色屏仅支持 0-3）

#### display.line(x0, y0, x1, y1, color)
绘制直线。

```lua
display.line(0, 0, 199, 199, 1)  -- 绘制对角线
```

#### display.rect(x, y, w, h, color)
绘制矩形边框。

```lua
display.rect(10, 10, 100, 50, 1)  -- 绘制矩形框
```

#### display.fill_rect(x, y, w, h, color)
绘制填充矩形。

```lua
display.fill_rect(20, 20, 80, 40, 1)  -- 绘制实心矩形
```

#### display.circle(x, y, r, color)
绘制圆形边框。

```lua
display.circle(100, 100, 50, 1)  -- 绘制空心圆
```

#### display.fill_circle(x, y, r, color)
绘制填充圆形。

```lua
display.fill_circle(100, 100, 30, 1)  -- 绘制实心圆
```

#### display.text(x, y, text, size, color[, background])
显示文本（ASCII + UTF-8 中文）。

```lua
display.text(10, 50, "Hello", 2)     -- 小字
display.text(10, 100, "World", 3)    -- 中字
display.text(10, 150, "!", 4)        -- 大字
display.text(10, 30, "Red", 3, 3)    -- 红色文字（color: 0=黑,1=白,2=黄,3=红,4=蓝,5=绿）
display.text(10, 80, "纪念日", 3)    -- 中文（UTF-8）
display.text(10, 120, "今日", 3, 0, 2) -- 黑字 + 黄色字格背景（用于压在色块上）
```

**参数**:
- `x, y`: 文本起始坐标
- `text`: 字符串内容（ASCII 或 UTF-8 中文混排）
- `size`: 字体大小 (1-4)
  - 1: 6×8 像素
  - 2: 12×16 像素
  - 3: 18×24 像素
  - 4: 24×32 像素
- `color`: 文字颜色（可选，默认黑色 0）
- `background`: 可选。省略时保持旧行为（ASCII 字格白底、中文只画前景）；
  指定 `0-5` 时字格用该颜色填满，适合在色块上显示文字；指定 `-1` 时透明，
  只画文字前景点。

**中文字体说明**:
- 中文使用内置 GB2312 点阵：`size 3` 对应 16x16，`size 4` 对应 24x24，与同尺寸
  ASCII 字体行高一致；`size 1/2` 也会用 16x16 渲染中文，但 ASCII 部分行高较小；
- 字库未收录的字符（如 emoji、生僻字）回退显示为 `?`；
- 字库文件位于 `/spiffs/fonts/`，需随文件系统镜像上传（见“中文字库”一节）。

#### display.show()
将缓冲区内容刷新到墨水屏。

```lua
display.show()  -- 执行刷新，约12秒
```

**重要**: 
- 调用此函数后才能看到显示效果
- 刷新约需12秒
- 建议刷新间隔≥30秒

#### 中文字库

设备内置全量 GB2312 点阵字库（6763 汉字 + 682 符号），文件随文件系统镜像
上传到 `/spiffs/fonts/`：

| 文件 | 说明 | 大小 |
|---|---|---|
| `gb2312_16.bin` | 16x16 点阵（94x94 网格，每字形 32 字节） | ≈ 276 KB |
| `gb2312_24.bin` | 24x24 点阵（每字形 72 字节） | ≈ 621 KB |
| `gb2312_map.bin` | Unicode→GB2312 映射表（7445 条） | ≈ 29 KB |

字库由 `tools/gen_gb2312_font.py` 从开源字体（Noto Sans SC，OFL 协议）生成，
生成后放入 `data/fonts/`。重新生成时执行：

```bash
python tools/gen_gb2312_font.py
```

### 2. time - 时间管理

#### time.get()
获取当前时间。

```lua
local hour, minute, second = time.get()
print(string.format("%02d:%02d:%02d", hour, minute, second))
```

**返回**: `hour` (0-23), `minute` (0-59), `second` (0-59)

#### time.delay(ms)
延迟指定毫秒数。

```lua
time.delay(1000)  -- 延迟1秒
```

**参数**: `ms` - 毫秒数

**注意**: 
- 不要在 `loop()` 中使用过长延迟
- 建议单次延迟 ≤ 5000ms

#### time.millis()
获取系统运行时间（毫秒）。

```lua
local start = time.millis()
-- 执行某些操作
local elapsed = time.millis() - start
print("耗时: " .. elapsed .. "ms")
```

### 2.5 sys - 系统信息

已移除 `sys.wake_source()`：统一休眠模型下按键唤醒由系统层处理，
模块 `setup()` 一律绘制，无需判断唤醒源。

#### sys.page_index()

获取当前模块页索引（`subpage_index`）。

#### sys.set_state(key, value) / sys.get_state(key)

跨深度休眠的少量状态读写（RTC 内存，**掉电丢失**），按键切换等需要记住
“当前显示位置”的场景使用：

```lua
sys.set_state("idx", 42)       -- 保存
local idx = sys.get_state("idx")  -- 读取，未保存时返回 0
```

- 按“模块 id + 键名”哈希隔离，不同模块互不干扰（最多 8 个槽位）；
- 深度休眠期间保持；完全掉电后清零（回退到默认/时间槽位逻辑即可）。

### 3. 标准 Lua 库

#### math 库
```lua
local angle = math.rad(45)      -- 角度转弧度
local x = math.sin(angle)       -- 正弦
local y = math.cos(angle)       -- 余弦
local r = math.sqrt(x*x + y*y)  -- 平方根
local n = math.random(1, 100)   -- 随机数 [1, 100]
local pi = math.pi              -- 圆周率
local abs = math.abs(-5)        -- 绝对值
```

#### string 库
```lua
local s = string.format("%02d:%02d", 9, 5)  -- "09:05"
local len = string.len("Hello")             -- 5
local upper = string.upper("hello")         -- "HELLO"
local lower = string.lower("HELLO")         -- "hello"
local sub = string.sub("Hello", 1, 3)       -- "Hel"
```

#### table 库
```lua
local t = {1, 2, 3}
table.insert(t, 4)        -- {1, 2, 3, 4}
local v = table.remove(t) -- v=4, t={1, 2, 3}
table.sort(t)             -- 排序
```

### 4. print - 调试输出

输出到串口（用于调试）。

```lua
print("调试信息")
print("值:", 42)
print("坐标:", x, y)
```

---

## 模块开发模式

> ⚠️ **统一休眠模型**：当前固件**不再调用模块 `loop()`**。设备执行完逻辑立即
> 深度休眠，周期刷新统一走"定时唤醒 → `setup()` 重绘"。下方旧示例中的
> `loop()` 仅供理解常驻运行模式，实际开发请改为在 `.cfg` 声明 `interval`
> 并用 `setup()` 绘制（见"深度休眠定时唤醒"）。

### 模式1: 静态显示
适用于不需要频繁更新的内容。

```lua
-- @name: 静态Logo
-- @version: 1.0.0
-- @description: 显示静态图案
-- @id: logo-static

function setup()
    display.clear()
    
    -- 绘制静态内容
    display.text(50, 80, "MiniEink", 3)
    display.rect(10, 10, 180, 180, 1)
    
    display.show()
end

function loop()
    -- 保持休眠，节省电量
    time.delay(60000)  -- 1分钟
end
```

**特点**:
- 仅在 `setup()` 中绘制一次
- `loop()` 保持长延迟
- 适合：Logo、标语、固定图案

### 模式2: 定时刷新
适用于需要周期性更新的内容。

```lua
-- @name: 定时时钟
-- @version: 1.0.0
-- @description: 每分钟更新时间
-- @id: clock-timer

local last_update = 0
local update_interval = 60000  -- 60秒

function setup()
    display.clear()
    display.show()
end

function loop()
    local now = time.millis()
    
    if now - last_update >= update_interval then
        last_update = now
        
        -- 更新显示
        display.clear()
        local h, m, s = time.get()
        display.text(50, 90, string.format("%02d:%02d", h, m), 3)
        display.show()
    end
    
    time.delay(1000)  -- 每秒检查一次
end
```

**特点**:
- 使用 `time.millis()` 计时
- 到达间隔才刷新
- 适合：时钟、倒计时

### 模式3: 条件触发
适用于状态变化时更新。

```lua
-- @name: 变化时钟
-- @version: 1.0.0
-- @description: 分钟变化时更新
-- @id: clock-change

local last_minute = -1

function setup()
    display.clear()
    display.show()
end

function loop()
    local h, m, s = time.get()
    
    -- 仅当分钟变化时更新
    if m ~= last_minute then
        last_minute = m
        
        display.clear()
        display.text(50, 90, string.format("%02d:%02d", h, m), 3)
        display.show()
    end
    
    time.delay(1000)
end
```

**特点**:
- 检测状态变化
- 仅在需要时刷新
- 适合：时钟、日期显示

### 模式4: 多页轮播
适用于需要显示多屏内容。

```lua
-- @name: 信息轮播
-- @version: 1.0.0
-- @description: 多页内容轮播
-- @id: info-carousel

local page = 0
local pages = 3
local page_interval = 30000  -- 30秒切换
local last_switch = 0

function setup()
    show_page(0)
end

function loop()
    local now = time.millis()
    
    if now - last_switch >= page_interval then
        page = (page + 1) % pages
        show_page(page)
        last_switch = now
    end
    
    time.delay(1000)
end

function show_page(p)
    display.clear()
    
    if p == 0 then
        display.text(60, 90, "Page 1", 3)
    elseif p == 1 then
        display.text(60, 90, "Page 2", 3)
    else
        display.text(60, 90, "Page 3", 3)
    end
    
    display.show()
end
```

---

## 最佳实践

### 1. 优化刷新策略
```lua
-- ✅ 好：按需刷新
if content_changed then
    display.clear()
    -- 绘制内容
    display.show()
end

-- ❌ 差：无条件刷新
display.clear()
-- 绘制内容
display.show()  -- 每次loop都刷新
```

### 2. 使用局部变量
```lua
-- ✅ 好：缓存重复计算
local center_x = WIDTH / 2
local center_y = HEIGHT / 2

for i = 1, 10 do
    display.circle(center_x, center_y, i * 10, 1)
end

-- ❌ 差：重复计算
for i = 1, 10 do
    display.circle(WIDTH / 2, HEIGHT / 2, i * 10, 1)
end
```

### 3. 合理使用延迟
```lua
-- ✅ 好：根据刷新间隔调整
function loop()
    if should_update() then
        update_display()
    end
    time.delay(1000)  -- 每秒检查
end

-- ❌ 差：无延迟
function loop()
    update_display()  -- 无延迟，刷新过频
end
```

### 4. 文本居中显示
```lua
function text_centered(y, text, size)
    -- 估算文本宽度（6像素 * size * 字符数）
    local char_width = 6 * size
    local text_width = string.len(text) * char_width
    local x = (WIDTH - text_width) / 2
    display.text(x, y, text, size)
end

-- 使用
text_centered(90, "Hello", 3)
```

### 5. 使用配置默认值
```lua
-- ✅ 好：提供默认值
local interval = CONFIG.interval or 60
local format = CONFIG.time_format or "24h"

-- ❌ 差：直接使用可能为nil
local interval = CONFIG.interval  -- 可能为nil
```

### 6. 避免频繁创建表
```lua
-- ✅ 好：复用表
local buffer = {}

function loop()
    -- 清空复用
    for k in pairs(buffer) do buffer[k] = nil end
    -- 使用buffer
end

-- ❌ 差：每次创建新表
function loop()
    local buffer = {}  -- 每次分配新内存
end
```

### 6.5 大数据表的内存优化

ESP32-C3 的 Lua 堆有限（无自定义内存上限，堆耗尽会报 `not enough memory`）。
内置大量静态数据时：

- ✅ 用**扁平数组**：每条数据合并成单个字符串（如 `"名言\t作者"`），需要时再拆分；
- ❌ 避免"每项一个小表 + 多个字符串对象"（对象数量 × 431 会显著放大内存占用）；
- 脚本由设备端流式加载（`luaL_loadfile`），无需自行处理大文件。

### 7. 错误处理
```lua
-- ✅ 好：保护关键代码
function loop()
    local success, err = pcall(function()
        update_display()
    end)
    
    if not success then
        print("错误:", err)
        display.clear()
        display.text(10, 90, "Error", 2)
        display.show()
    end
    
    time.delay(1000)
end
```

---

## 示例模块

### 示例1: 大字时钟

```lua
-- @name: 大字时钟
-- @version: 1.0.0
-- @author: MiniEink
-- @description: 全屏显示时间
-- @id: clock-large

local last_minute = -1

function setup()
    display.clear()
    display.show()
end

function loop()
    local h, m, s = time.get()
    
    if m ~= last_minute then
        last_minute = m
        
        -- 读取配置
        local format = CONFIG.time_format or "24h"
        
        -- 12小时制转换
        if format == "12h" then
            h = h % 12
            if h == 0 then h = 12 end
        end
        
        display.clear()
        
        -- 居中显示时间
        local time_str = string.format("%02d:%02d", h, m)
        display.text(40, 85, time_str, 4)  -- 大字
        
        display.show()
    end
    
    time.delay(1000)
end
```

**配置文件** `clock-large.cfg`:
```json
[
  {
    "key": "time_format",
    "type": "select",
    "label": "时间格式",
    "options": [
      {"label": "24小时", "value": "24h"},
      {"label": "12小时", "value": "12h"}
    ],
    "default": "24h",
    "desc": "选择时间显示格式"
  }
]
```

### 示例2: 简单计数器

```lua
-- @name: 计数器
-- @version: 1.0.0
-- @author: MiniEink
-- @description: 每秒递增计数器
-- @id: counter-simple

local counter = 0
local last_update = 0

function setup()
    counter = CONFIG.start or 0
    display.clear()
    display.show()
end

function loop()
    local interval = (CONFIG.interval or 1) * 1000
    local now = time.millis()
    
    if now - last_update >= interval then
        last_update = now
        counter = counter + 1
        
        display.clear()
        display.text(70, 85, tostring(counter), 4)
        display.show()
    end
    
    time.delay(100)
end
```

**配置文件** `counter-simple.cfg`:
```json
[
  {
    "key": "start",
    "type": "slider",
    "label": "起始值",
    "min": 0,
    "max": 1000,
    "step": 1,
    "default": 0,
    "desc": "计数器起始值"
  },
  {
    "key": "interval",
    "type": "slider",
    "label": "间隔(秒)",
    "min": 1,
    "max": 60,
    "step": 1,
    "default": 1,
    "desc": "递增间隔"
  }
]
```

### 示例3: 状态指示器

```lua
-- @name: 运行时间
-- @version: 1.0.0
-- @author: MiniEink
-- @description: 显示系统运行时间
-- @id: uptime-display

function setup()
    display.clear()
    display.show()
end

function loop()
    local uptime = time.millis() / 1000  -- 转为秒
    local minutes = math.floor(uptime / 60)
    local seconds = math.floor(uptime % 60)
    
    display.clear()
    
    -- 标题
    display.text(50, 60, "Uptime", 2)
    
    -- 时间
    local time_str = string.format("%d:%02d", minutes, seconds)
    display.text(50, 100, time_str, 3)
    
    display.show()
    
    time.delay(1000)
end
```

---

## 常见问题

### 模块无法加载

**症状**: 小程序中看不到模块

**排查**:
1. 检查文件头元数据格式：
   - 必须使用 `-- @key: value` 格式
   - `@name:`, `@version:`, `@id:` 必须存在
2. 确认文件名和 `@id` 一致，都使用连字符
   - ✅ `clock-simple.lua` + `@id: clock-simple`
   - ❌ `clock_simple.lua` + `@id: clock_simple`
3. 检查 Lua 语法错误
   - 使用 `print()` 在 `setup()` 中输出调试信息
   - 查看串口输出

### 配置不生效

**症状**: 修改配置后模块行为不变

**排查**:
1. 确认配置文件已上传到设备
2. 检查配置文件名与 Lua 文件名一致
3. 验证 JSON 格式正确（使用 JSON 校验工具）
4. 确认 Lua 中正确读取 `CONFIG` 表：
   ```lua
   local value = CONFIG.key_name or default_value
   ```
5. 对于布尔值，使用正确的读取方式：
   ```lua
   local flag = false
   if CONFIG.flag ~= nil then
       flag = CONFIG.flag
   end
   ```

### 显示不更新

**症状**: 调用了绘图函数但屏幕没变化

**排查**:
1. 确认调用了 `display.show()`
   ```lua
   display.clear()
   display.text(50, 90, "Hello", 3)
   display.show()  -- 必须调用
   ```
2. 检查坐标是否在范围内 (0-199)
3. 验证颜色值 (0=黑, 1=白, 2=黄, 3=红)
4. 确认在 `display.clear()` 后重新绘制了内容

### 刷新太频繁

**症状**: 屏幕频繁刷新，设备响应慢

**原因**: `loop()` 中每次都调用 `display.show()`

**解决**:
```lua
-- ❌ 错误：每次loop都刷新
function loop()
    display.clear()
    display.text(50, 90, "Hello", 3)
    display.show()  -- 每次都刷新
    time.delay(100)
end

-- ✅ 正确：添加条件判断
local last_update = 0
local interval = 60000  -- 60秒

function loop()
    local now = time.millis()
    
    if now - last_update >= interval then
        last_update = now
        display.clear()
        display.text(50, 90, "Hello", 3)
        display.show()
    end
    
    time.delay(1000)
end
```

### 性能问题

**症状**: 模块运行缓慢或卡顿

**优化方法**:
1. 减少刷新频率（建议≥30秒）
2. 避免在 `loop()` 中做复杂计算
3. 使用局部变量缓存结果
4. 增加 `time.delay()` 延迟
5. 避免创建大量表

---

## API 快速参考

### 显示 API

| 函数 | 参数 | 说明 |
|---|---|---|
| `display.clear()` | - | 清空屏幕 |
| `display.pixel(x, y, c)` | x, y, color | 绘制像素(0=黑,1=白,2=黄,3=红,4=蓝,5=绿) |
| `display.line(x0, y0, x1, y1, c)` | 起点, 终点, color | 绘制直线 |
| `display.rect(x, y, w, h, c)` | 位置, 尺寸, color | 绘制矩形框 |
| `display.fill_rect(x, y, w, h, c)` | 位置, 尺寸, color | 填充矩形 |
| `display.circle(x, y, r, c)` | 圆心, 半径, color | 绘制圆形框 |
| `display.fill_circle(x, y, r, c)` | 圆心, 半径, color | 填充圆形 |
| `display.text(x, y, str, size, c[, bg])` | 位置, 文本, 大小, 颜色, 背景色 | 显示文本(ASCII/中文)；背景色可选，-1=透明 |
| `display.show()` | - | 刷新显示(约12秒) |

### 时间 API

| 函数 | 返回值 | 说明 |
|---|---|---|
| `time.get()` | hour, minute, second | 获取当前时间 |
| `time.millis()` | 毫秒数 | 系统运行时间 |
| `time.delay(ms)` | - | 延迟毫秒 |

### 配置 API

| 变量 | 类型 | 说明 |
|---|---|---|
| `CONFIG.key` | any | 读取配置值 |
| `WIDTH` | number | 屏幕宽度 (200) |
| `HEIGHT` | number | 屏幕高度 (200) |

### 标准库

| 库 | 常用函数 |
|----|----|
| `math` | `sin`, `cos`, `sqrt`, `abs`, `floor`, `ceil`, `random`, `pi` |
| `string` | `format`, `len`, `upper`, `lower`, `sub` |
| `table` | `insert`, `remove`, `sort` |
| `print` | 调试输出到串口 |

---

## 开发检查清单

### 模块创建
- [ ] 文件名使用连字符 `-`，不使用下划线 `_`
- [ ] 文件头包含完整元数据 (`@name:`, `@version:`, `@id:`, `@description:`)
- [ ] `@id` 与文件名一致
- [ ] `@description` 不超过 128 字节（约42个中文字符）

### 代码质量
- [ ] 实现了 `setup()` 函数（统一模型下必需，`loop()` 不再被调用）
- [ ] 合理使用 `time.delay()` 避免空转
- [ ] 使用局部变量而非全局变量
- [ ] 为配置项提供默认值
- [ ] 添加了必要的错误处理

### 显示优化
- [ ] 避免频繁刷新（建议≥30秒）
- [ ] 每次刷新前调用 `display.clear()`
- [ ] 仅在内容变化时刷新
- [ ] 坐标在有效范围内 (0-199)

### 配置文件
- [ ] 配置文件名与 Lua 文件名一致
- [ ] JSON 格式正确
- [ ] 配置项有合理的默认值
- [ ] 配置说明清晰（`desc` 字段）

### 测试
- [ ] 在设备上测试模块加载
- [ ] 验证配置修改生效
- [ ] 检查显示是否正常
- [ ] 确认无性能问题
- [ ] 测试长时间运行稳定性

---

## 故障排查

### 调试技巧

1. **使用 print() 输出**
   ```lua
   function setup()
       print("模块启动")
       print("配置值:", CONFIG.key)
   end
   
   function loop()
       local h, m, s = time.get()
       print("时间:", h, m, s)
       time.delay(1000)
   end
   ```

2. **检查配置加载**
   ```lua
   function setup()
       for k, v in pairs(CONFIG) do
           print("配置:", k, "=", v)
       end
   end
   ```

3. **显示错误信息**
   ```lua
   function loop()
       local success, err = pcall(function()
           -- 你的代码
       end)
       
       if not success then
           print("错误:", err)
           display.clear()
           display.text(10, 90, "Error", 2)
           display.show()
       end
   end
   ```

---

**版本**: 1.0.0  
**适用设备**: MiniEink (ESP32-C3 墨水屏)

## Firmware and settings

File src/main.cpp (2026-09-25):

#include "common.h"
#include "esp_sleep.h"
#include "sleep_manager.h"
#include "ble_config.h"
#include "app_control.h"
#include "module_registry.h"
#include "lua_hardware_api.h"
#include "time_calibration.h"
#include <Preferences.h>
#include "battery.h"
#include "cmd_handler.h"
#include <SPIFFS.h>
#include "eink_display.h"
#include "epd_async.h"

// Button status enumeration for better code readability
enum ButtonStatus {
  BTN_NONE = 0,      // No action
  BTN_CLICK = 1,     // Short click (subpage switch)
  BTN_MODULE = 2,    // Long press - switch module
  BTN_BLE = 3        // Long press - toggle BLE config
};

ButtonStatus btn_status = BTN_NONE;
uint32_t tm_chk_bat=0;
uint32_t key_up_hold=0,key_down_hold=0;
bool key_up_triggered=false,key_down_triggered=false;
// 休眠唤醒后长按切模块：等待 KEY_DOWN 释放再进入深度休眠
// （按键还按着时不能直接休眠，低电平 GPIO 唤醒会立刻再次唤醒）
static bool s_sleep_after_wake_switch = false;

void main_load_config(){
  Preferences prefs;
  prefs.begin("bottle", true);
  page_index = prefs.getInt("page_index");
  prefs.end();
}

void main_save_config(){
  Preferences prefs;
  prefs.begin("bottle", false);
  prefs.putInt("page_index",page_index);
  prefs.end();

  // const module_descriptor_t* module = module_registry_get((uint8_t)page_index);
  // if (module && module->unload) {
  //   module->unload();
  // }
}

int32_t app_get_page_count(void) {
  return module_registry_count();
}

int32_t app_get_page_index(void) {
  return page_index;
}

int32_t app_get_subpage_index(void) {
  return subpage_index;
}

void app_set_subpage(int32_t subpage) {
  subpage_index = subpage;
}

bool app_set_module_enabled(int32_t page, bool enabled) {
  if (page < 0 || page >= module_registry_count()) {
    return false;
  }

  bool was_enabled = module_registry_is_enabled((uint8_t)page);
  module_registry_set_enabled((uint8_t)page, enabled);
  bool now_enabled = module_registry_is_enabled((uint8_t)page);
  if (was_enabled == now_enabled) {
    return now_enabled == enabled;
  }

  if (!now_enabled && page == page_index) {
    const module_descriptor_t* current = module_registry_get((uint8_t)page_index);
    if (current && current->unload) {
      current->unload();
    }
    page_index = module_registry_normalize_index(page_index);
    subpage_index = 0;
    const module_descriptor_t* next = module_registry_get((uint8_t)page_index);
    if (next && next->setup) {
      next->setup();
    }
  }

  return true;
}

void app_set_page(int32_t page, int32_t subpage) {
  if (page < 0 || page >= module_registry_count()) {
    return;
  }
  if (!module_registry_is_enabled((uint8_t)page)) {
    return;
  }

  if (page == page_index) {
    app_set_subpage(subpage);
    return;
  }

  const module_descriptor_t* current = module_registry_get((uint8_t)page_index);
  if (current && current->unload) {
    current->unload();
  }
  page_index = page;
  subpage_index = subpage;
  const module_descriptor_t* next = module_registry_get((uint8_t)page_index);
  if (next && next->setup) {
    next->setup();
  }

  Preferences prefs;
  prefs.begin("bottle", false);
  prefs.putInt("page_index", page_index);
  prefs.end();
}


// KEY_UP 短按动作：消费唤醒意图（KEY_UP 唤醒短按后进入休眠）；
// 模块"上一项"钩子（相册=上一张），无钩子则 subpage-1
static void key_up_short_press_action() {
  Serial.println("KEY_UP press detected");
  if (ble_config_is_enabled()) {
    return;
  }
  bool wake_short_press = (module_registry_consume_wake_key() == KEY_UP);
  const module_descriptor_t* current = module_registry_get((uint8_t)page_index);
  if (current && current->subpage_prev) {
    // 模块自定义"上一项"（如相册显示上一张）
    current->subpage_prev();
    Serial.println("KEY_UP: module prev action");
  } else if (!wake_short_press && subpage_index > 0) {
    subpage_index--;
    Serial.printf("Subpage: %d\n", subpage_index);
  }
  if (wake_short_press) {
    Serial.println("KEY_UP wake short press -> enter deep sleep");
    enter_deep_sleep();
  }
}

// KEY_DOWN 短按动作：消费唤醒意图（KEY_DOWN 唤醒短按后进入休眠）；
// 模块"下一项"钩子（相册=下一张），无钩子则 subpage+1
static void key_down_short_press_action() {
  Serial.println("KEY_DOWN press detected");
  if (ble_config_is_enabled()) {
    Serial.println("KEY_DOWN: ignored while BLE enabled");
    return;
  }
  bool wake_short_press = (module_registry_consume_wake_key() == KEY_DOWN);
  const module_descriptor_t* current = module_registry_get((uint8_t)page_index);
  if (current && current->subpage_next) {
    // 模块自定义"下一项"（如相册显示下一张）
    current->subpage_next();
    Serial.println("KEY_DOWN: module next action");
  } else if (!wake_short_press) {
    subpage_index++;
    Serial.printf("Subpage: %d\n", subpage_index);
  }
  if (wake_short_press) {
    Serial.println("KEY_DOWN wake short press -> enter deep sleep");
    enter_deep_sleep();
  }
}

void check_btn(){
  uint32_t now = millis();

  // 深度休眠按键唤醒：若唤醒按键在轮询开始前已松开（setup 显示耗时较长），
  // 补一次短按事件，避免按键事件丢失（若仍按住则由下方轮询正常判定长按）
  uint8_t wake_key = module_registry_peek_wake_key();
  if (wake_key != 0 && digitalRead(wake_key) != LOW) {
    if (wake_key == KEY_DOWN) {
      key_down_short_press_action();  // 内部消费 KEY_DOWN 唤醒意图并休眠
    } else {
      key_up_short_press_action();    // 内部消费 KEY_UP 唤醒意图并休眠
    }
  }

  if (digitalRead(KEY_UP) == LOW) {
    delay(100); // Debounce delay
    if (digitalRead(KEY_UP) == LOW && key_up_triggered==false) {
      if (key_up_hold>0) {
        uint32_t hold_duration = now - key_up_hold;
        // 长按（3秒）：开关 BLE 配置（按住即触发，保持原行为）
        if (hold_duration >= 3000) {
          key_up_triggered=true;
          key_up_hold = 0;
          Serial.println("KEY_UP long press detected");
          btn_status = BTN_BLE;
        }
      }
      else {
        key_up_hold=millis();
      }
    }
  }
  else {
    if (key_up_hold > 0 && key_up_triggered==false) {
      uint32_t hold_duration = now - key_up_hold;
      key_up_hold = 0;
      key_up_short_press_action();
    }
    key_up_triggered=false;
  }
  if (digitalRead(KEY_DOWN) == LOW) {
    delay(100); // Debounce delay
    if (digitalRead(KEY_DOWN) == LOW && key_down_triggered==false) {
      if (key_down_hold>0) {
        uint32_t hold_duration = now - key_down_hold;
        // 长按（3秒）：切换下一个模块（按住即触发，与 KEY_UP 一致）
        if (hold_duration >= 3000) {
          key_down_triggered=true;
          key_down_hold = 0;
          Serial.println("KEY_DOWN long press detected");
          btn_status = BTN_MODULE;
        }
      }
      else {
        key_down_hold=millis();
      }
    }
  }
  else {
    if (key_down_hold > 0 && key_down_triggered==false) {
      uint32_t hold_duration = now - key_down_hold;
      key_down_hold = 0;
      key_down_short_press_action();
    }
    key_down_triggered=false;
  }
 
  if (btn_status == BTN_CLICK){
    btn_status = BTN_NONE;
    if (ble_config_is_enabled()) {
      return;
    }
    subpage_index++;
  }
  else if (btn_status == BTN_MODULE){
    if (ble_config_is_enabled()) {
      btn_status = BTN_NONE;
      return;
    }
    btn_status = BTN_NONE;
    // 长按已消费唤醒意图：切换模块时清除，避免残留标记影响下次按键
    uint8_t wake_key = module_registry_consume_wake_key();
    bool wake_switch = (wake_key == KEY_DOWN);
    const module_descriptor_t* current = module_registry_get((uint8_t)page_index);
    if (current && current->unload) {
      current->unload();
    }

    page_index = module_registry_next_enabled(page_index);
    if (page_index < 0) {
      page_index = module_registry_normalize_index(0);
    }
    subpage_index=0;

    const module_descriptor_t* next = module_registry_get((uint8_t)page_index);
    if (next && next->setup) {
      next->setup();
    }
    main_save_config();
    if (wake_switch) {
      // 休眠唤醒后的长按：切换完成后等按键释放再进入深度休眠
      s_sleep_after_wake_switch = true;
      Serial.println("KEY_DOWN wake long press: module switched, sleep after key release");
    }

  }
  else if (btn_status == BTN_BLE){
    btn_status = BTN_NONE;
    // 长按已消费唤醒意图：进入 BLE 时清除，避免残留标记影响下次按键
    module_registry_consume_wake_key();
    ble_config_toggle();
    // 统一模型：BLE 退出后立即休眠（见 loop 中 ble_config_should_sleep_after_disconnect），
    // 不重绘屏幕；新配置在下次唤醒的 setup 中生效
  }
}

void setup() {
  setCpuFrequencyMhz(80);
  Serial.begin(115200);

#if EPD_PROBE_BUSY_ON_BOOT
  // ==== 临时诊断：唤醒后、任何 GPIO/SPI 初始化之前先读 BUSY 原始电平 ====
  // 1 = 面板当时已空闲（说明面板没问题，是唤醒后的初始化动作干扰了它）
  // 0 = 面板当时仍处于忙态（刷新在休眠期间没走完）
  delay(50);
  Serial.printf("[EPD] wake probe: cause=%d pending=%d\n",
                (int)esp_sleep_get_wakeup_cause(), epdAsyncIsPending() ? 1 : 0);
  Serial.printf("[EPD] wake probe: BUSY raw=%d (t=0 ms)\n", epdPanelBusyRaw());
  delay(300);
  Serial.printf("[EPD] wake probe: BUSY raw=%d (t=300 ms)\n", epdPanelBusyRaw());
#endif

  pinMode(KEY_UP, INPUT);
  pinMode(KEY_DOWN, INPUT);
  pinMode(BLE_LIGHT, OUTPUT);
  digitalWrite(BLE_LIGHT, HIGH);

  SPIFFS.begin(true);

  // 预加载 GB2312 字库映射表：开机内存最充足时加载，
  // 避免 BLE 会话中首次绘制中文时堆不足导致全部显示为 '?'
  lua_hardware_preload_gb2312();

  // 释放上次异步刷屏休眠期间保持的面板控制引脚（必须在初始化 SPI 之前）
  epdAsyncReleasePins();

  eink_display_init();

#if EPD_PROBE_BUSY_ON_BOOT
  Serial.printf("[EPD] wake probe: BUSY raw=%d (after init)\n", epdPanelBusyRaw());

  // ==== 临时诊断（确认该屏 BUSY 读法，定位完可删除本段）====
  // 上电冷启动时触发一次全白刷新，打印 BUSY 原始电平时间线：
  // 正常应是"刷新期间某个电平、刷新结束后翻到另一个电平并稳定"
  if (esp_sleep_get_wakeup_cause() == ESP_SLEEP_WAKEUP_UNDEFINED) {
    Serial.println("[EPD] probe: cold boot, measuring BUSY timeline");
    eink_display_white();
    epdAsyncProbeBusy(30000, 250);
    epdAsyncPowerOffNow();
    epdAsyncClearPending();
  }
#endif

  // // 6. 检查并执行自动 OTA 更新（如果有 firmware.bin）
  // if (auto_ota_check_and_update()) {
  //   // OTA 更新执行中或失败，函数内部会处理重启或清理
  //   // 如果到这里说明更新失败，继续正常启动
  //   log_e("[Setup] OTA update failed or completed, continuing normal boot");
  // }

  // 7. 恢复时区设置
  restore_timezone();

  // 8. 初始化时间校准模块
  TimeCalibration::init();

  main_load_config();

  module_registry_init();

  page_index = module_registry_normalize_index(page_index);

  // 异步刷屏唤醒：上次休眠时面板仍在刷新。定时唤醒时刻就是按刷新时长选的，
  // 此刻刷新窗口已经过去，直接断电 + 面板休眠即可（不再依赖 BUSY 电平判断，
  // 部分面板/接线读不到空闲电平，会白白多等一个超时）
  if (epdAsyncIsPending()) {
    Serial.println("[EPD] async refresh wake: refresh window elapsed, power off panel");
    epdAsyncPowerOffNow();
    epdAsyncClearPending();
    enter_deep_sleep();
  }

  // 电池保护：每次开机（上电 / 按键 / 定时唤醒）都先检测电压。
  // 低于 3.1V 时不执行任何模块逻辑（不绘制、不进 BLE 配置），直接深度休眠；
  // 保留按键与定时唤醒，电压恢复后再次开机即可自动继续正常运行。
  check_battery_init();
  int battery_mv = battery_get_mv();
  if (battery_mv < BATTERY_LOW_MV) {
    Serial.printf("Battery too low: %d mV (< %d), skip all actions, enter deep sleep\n",
                  battery_mv, BATTERY_LOW_MV);
    // 若由按键唤醒且按键仍按住，等释放后再休眠，
    // 避免 GPIO 低电平唤醒源立即再次触发形成开机循环
    while (digitalRead(KEY_UP) == LOW || digitalRead(KEY_DOWN) == LOW) {
      delay(50);
    }
    enter_deep_sleep();
  }

  // 统一休眠策略：
  // - 按键唤醒：记录唤醒按键，跳过模块 setup 绘制，由 check_btn 判定短按/长按
  //   （短按 → 上一项/下一项后休眠；长按 → 切换模块后休眠 / 开关 BLE 保持唤醒）
  // - 上电/定时唤醒：模块 setup 绘制当前内容，执行完立即进入深度休眠
  if (esp_sleep_get_wakeup_cause() == ESP_SLEEP_WAKEUP_GPIO) {
    uint64_t gpio_status = esp_sleep_get_gpio_wakeup_status();
    if (gpio_status & (1ULL << KEY_DOWN)) {
      module_registry_mark_wake_key(KEY_DOWN);
      Serial.println("Woke by KEY_DOWN");
    } else if (gpio_status & (1ULL << KEY_UP)) {
      module_registry_mark_wake_key(KEY_UP);
      Serial.println("Woke by KEY_UP");
    }
  } else {
    // 非按键唤醒：清除可能残留的标记，避免误触发"唤醒短按"
    module_registry_consume_wake_key();

    const module_descriptor_t* module = module_registry_get((uint8_t)page_index);
    if (module && module->setup) {
      Serial.println("Setting up module: " + String(module->name));
      module->setup();
    }

    // 非按键唤醒：逻辑执行完毕，立即休眠（BLE 只能通过长按 KEY_UP 进入）
    Serial.println("Non-key wake: module drawn, entering deep sleep");
    enter_deep_sleep();
  }
}

void loop() {

  check_btn();

  // 面板断电兜底：异步刷新后若系统未进入休眠（实时交互/BLE），刷新结束即断电
  epdAsyncMaintain();

  // 休眠唤醒长按切模块：KEY_DOWN 释放后进入深度休眠
  if (s_sleep_after_wake_switch && digitalRead(KEY_DOWN) != LOW) {
    s_sleep_after_wake_switch = false;
    enter_deep_sleep();
  }

  check_cmd();

  ble_config_update();

  // 蓝牙会话结束（连接过并已断开/退出）→ 立即休眠，不再等待空闲超时
  if (ble_config_should_sleep_after_disconnect()) {
    Serial.println("BLE: session ended, entering deep sleep");
    ble_config_stop();  // 若仍在广播，停止 BLE 栈
    digitalWrite(BLE_LIGHT, HIGH);
    enter_deep_sleep();
  }

  if (ble_config_is_enabled()) {
    delay(30);
    return;
  }

  // 非 BLE 模式仅存在于按键唤醒判定期间（随后必然休眠）。
  // 模块不再有常驻 loop：周期刷新统一由深度休眠定时唤醒 → setup 驱动
  delay(20);  // ≥ tickless idle 入睡阈值（8ms @ 1000Hz），等待期间可 light sleep
}

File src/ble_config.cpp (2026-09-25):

#include "ble_config.h"
#include "ble_security.h"
#include "app_control.h"
#include "common.h"
#include "module_registry.h"
#include "sleep_manager.h"
#include "time_calibration.h"
#include "gallery.h"
#include "battery.h"
#include "eink_display.h"
#include "epd_async.h"
#include <Arduino.h>
#include <NimBLEDevice.h>
#include <sys/time.h>
#include <time.h>

// RTC 内存变量，深度休眠期间保持
RTC_DATA_ATTR int rtc_timezone_offset = 0;
RTC_DATA_ATTR bool rtc_timezone_valid = false;

// 设置时区的辅助函数
void set_timezone(int offset) {
    char tz_str[16];
    snprintf(tz_str, sizeof(tz_str), "UTC%+d", -offset);
    setenv("TZ", tz_str, 1);
    tzset();

    // 保存到 RTC 内存（深度休眠期间保持）
    rtc_timezone_offset = offset;
    rtc_timezone_valid = true;

    // 同时持久化到 NVS（完全掉电后也能恢复）
    save_config_ns("system", "tz_offset", offset);
}

// 恢复时区设置（在启动时调用）
void restore_timezone() {
    if (rtc_timezone_valid) {
        char tz_str[16];
        snprintf(tz_str, sizeof(tz_str), "UTC%+d", -rtc_timezone_offset);
        setenv("TZ", tz_str, 1);
        tzset();
        Serial.printf("Restored timezone: UTC%+d (RTC)\n", rtc_timezone_offset);
        return;
    }

    // RTC 内存丢失（如完全掉电）时，从 NVS 恢复
    int saved = load_config_ns("system", "tz_offset");
    if (saved != 0) {
        set_timezone(saved);  // 同时回写 RTC 内存
        Serial.printf("Restored timezone: UTC%+d (NVS)\n", saved);
    }
}

#include <Preferences.h>
#include <base64.h>
#include <sys/stat.h>

#define BLE_SERVICE_UUID "8c0b8a10-7e3d-4df7-9a2a-1d8d46f8b100"
#define BLE_CONFIG_CHAR_UUID "8c0b8a11-7e3d-4df7-9a2a-1d8d46f8b100"
#define BLE_STATUS_CHAR_UUID "8c0b8a12-7e3d-4df7-9a2a-1d8d46f8b100"
#define BLE_PASSWORD_CHAR_UUID "8c0b8a13-7e3d-4df7-9a2a-1d8d46f8b100"
#define BLE_AUTH_CHAR_UUID "8c0b8a14-7e3d-4df7-9a2a-1d8d46f8b100"

static NimBLECharacteristic* s_status_char = nullptr;
static NimBLECharacteristic* s_password_char = nullptr;
static NimBLECharacteristic* s_auth_char = nullptr;
static NimBLEServer* s_ble_server = nullptr;
static NimBLEAdvertising* s_ble_advertising = nullptr;
static String s_pending_cmd;
static bool s_has_pending_cmd = false;
static bool s_client_connected = false;
bool s_ble_enabled = false;
// 本次 BLE 会话是否发生过连接（连接过又在会话结束/断开 → 立即休眠省电）
static bool s_ble_had_connection = false;
// 连接已结束且应休眠（重新连接时清除）
static bool s_ble_sleep_after_disconnect = false;
// BLE 开启时刻（无连接超时计时起点，毫秒）
static uint32_t s_ble_start_ms = 0;
// BLE 开启后无连接超时：写死 60 秒（统一休眠模型，不再依赖 sleep_sec 空闲超时）
#define BLE_NO_CONNECT_TIMEOUT_MS (60UL * 1000UL)
static bool s_ble_initialized = false;

// 安全管理器
static DeviceSecurity deviceSecurity;

// File upload state
static bool s_upload_in_progress = false;
static String s_upload_module_id;
static String s_upload_filename;
static size_t s_upload_size = 0;
static size_t s_upload_received = 0;
static FILE* s_upload_file = nullptr;

// Config definition upload state
static bool s_config_def_in_progress = false;

// Color display state
static bool s_show_color = false;
static uint8_t s_color_r = 0;
static uint8_t s_color_g = 0;
static uint8_t s_color_b = 0;
static String s_config_def_module_id;
static String s_config_def_buffer;
static size_t s_config_def_size = 0;
static size_t s_config_def_received = 0;

// Gallery image upload state
static bool s_gallery_upload_in_progress = false;
static String s_gallery_upload_filename;
static size_t s_gallery_upload_size = 0;
static size_t s_gallery_upload_received = 0;
static uint8_t* s_gallery_upload_buffer = nullptr;
static size_t s_gallery_upload_chunk_size = 0;
static size_t s_gallery_upload_total_chunks = 0;
static uint8_t* s_gallery_upload_chunk_flags = nullptr;
static uint8_t* s_gallery_upload_decode_buf = nullptr;

// Simple base64 decode table
static const char base64_chars[] = "ABCDEFGHIJKLMNOPQRSTUVWXYZabcdefghijklmnopqrstuvwxyz0123456789+/";

static int base64_decode_char(char c) {
    if (c >= 'A' && c <= 'Z') return c - 'A';
    if (c >= 'a' && c <= 'z') return c - 'a' + 26;
    if (c >= '0' && c <= '9') return c - '0' + 52;
    if (c == '+') return 62;
    if (c == '/') return 63;
    return -1;
}

static size_t base64_decode(const char* input, size_t input_len, uint8_t* output) {
    size_t output_len = 0;
    uint32_t buffer = 0;
    int bits = 0;

    for (size_t i = 0; i < input_len; i++) {
        if (input[i] == '=') break;

        int value = base64_decode_char(input[i]);
        if (value < 0) continue;

        buffer = (buffer << 6) | value;
        bits += 6;

        if (bits >= 8) {
            bits -= 8;
            output[output_len++] = (buffer >> bits) & 0xFF;
        }
    }

    return output_len;
}
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

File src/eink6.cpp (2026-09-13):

#include "common.h"   // INK6 宏在此定义，eink6.cpp 需先包含才能正确条件编译

#ifdef INK6

#include <Arduino.h>
#include <SPI.h>
#include "eink6.h"
#include "GUI_Paint.h"
#include "epd_async.h"

// 6 色画布：240x240，4bpp 打包（2 像素/字节），供 GUI_Paint 绘制后整帧送屏
unsigned char BlackImage[ALLSCREEN_BYTES];


// Pin assignment - based on board selection
// 默认值 = 当前硬件接线：这些全局在 initPins() 之前（如开机释放引脚保持）也要可用
static int PIN_EPD_MOSI = 7;
static int PIN_EPD_CLK = 6;
static int PIN_EPD_BUSY = 10;
static int PIN_EPD_DC = 4;
static int PIN_EPD_CS = 5;
static int PIN_EPD_RST = 3;

void initPins() {

    // 新硬件 6 色屏引脚定义（ESP32-C3）
    PIN_EPD_MOSI = 7;
    PIN_EPD_CLK = 6;
    PIN_EPD_BUSY = 10;
    PIN_EPD_DC = 4;
    PIN_EPD_CS = 5;
    PIN_EPD_RST = 3;
    Serial.println("[BOARD] EPD pins: MOSI=7 CLK=6 BUSY=10 DC=4 CS=5 RST=3");

}

// Set false to run normal panel flow and draw color bars.
static const bool SAFE_DIAG_MODE = false;

// Most EPDs use BUSY low-active (LOW=busy, HIGH=idle). Some panels are opposite.
static bool gBusyActiveLevelLow = true;
static bool gIgnoreBusy = false;

// false: normal init, true: apply factory water-ripple init sequence.
static const bool USE_WATER_RIPPLE_INIT = false;

enum WaterRippleProfile : uint8_t {
    WATER_RIPPLE_FACTORY = 0,
    WATER_RIPPLE_NEW = 1,
};

// Select which water-ripple initialization profile to use.
static const WaterRippleProfile ACTIVE_WATER_RIPPLE_PROFILE = WATER_RIPPLE_NEW;

static const uint32_t BUSY_TIMEOUT_INIT_MS = 10000;
static const uint32_t BUSY_TIMEOUT_POWER_MS = 10000;
static const uint32_t BUSY_TIMEOUT_REFRESH_MS = 40000;
// 断电/深睡阶段的等待上限：面板已在睡眠或停在非初始化态时，BUSY 可能一直是"忙"
// 电平（四色板实测唤醒后 BUSY 恒为 0），这里取短值兜底，避免每次补断电白等
static const uint32_t POWEROFF_WAIT_MS = 2000;

// ====================== 异步刷屏钩子（见 epd_async.h）======================

// 面板刷新是否已结束（BUSY 回到空闲电平）
bool epdPanelIsIdle(void) {
  if (gIgnoreBusy) {
    return true;
  }
  const int busyLevel = gBusyActiveLevelLow ? LOW : HIGH;
  return digitalRead(PIN_EPD_BUSY) != busyLevel;
}

// 刷新结束：关闭面板电源并让面板进入深度休眠
void epdPanelPowerOff(void) {
  Serial.println("[EPD] stage: power off + panel deep sleep");
  // 刷新结束的等待已由 epdAsyncPowerOffNow()/epdAsyncMaintain() 处理，这里只断电
  epdWriteCommand(0x02);  // Power OFF
  epdWriteData(0x00);
  epdWaitBusyStage("Power OFF", POWEROFF_WAIT_MS);
  delay(20);
  epdEnterDeepSleep();
  Serial.println("[EPD] panel powered off and in deep sleep");
}

int epdPanelBusyRaw(void) {
  return digitalRead(PIN_EPD_BUSY);
}

void epdPanelHoldPins(bool hold) {
  if (hold) {
    // 休眠前把控制脚拉到空闲电平再保持
    digitalWrite(PIN_EPD_CS, HIGH);
    digitalWrite(PIN_EPD_DC, HIGH);
    digitalWrite(PIN_EPD_RST, HIGH);
  }
  const int pins[] = {
    PIN_EPD_RST, PIN_EPD_DC, PIN_EPD_CS, PIN_EPD_CLK, PIN_EPD_MOSI
  };
  epdAsyncHoldPinsImpl(pins, sizeof(pins) / sizeof(pins[0]), hold);
}

static inline void epdSelect() {
    digitalWrite(PIN_EPD_CS, LOW);
}

static inline void epdDeselect() {
    digitalWrite(PIN_EPD_CS, HIGH);
}

void diagPrintBusyWithPullModes() {
    pinMode(PIN_EPD_BUSY, INPUT);
    delay(3);
    int vInput = digitalRead(PIN_EPD_BUSY);

    pinMode(PIN_EPD_BUSY, INPUT_PULLUP);
    delay(3);
    int vPullup = digitalRead(PIN_EPD_BUSY);

    pinMode(PIN_EPD_BUSY, INPUT_PULLDOWN);
    delay(3);
    int vPulldown = digitalRead(PIN_EPD_BUSY);

    Serial.printf("[EPD] BUSY sample: IN=%d PU=%d PD=%d\n", vInput, vPullup, vPulldown);
}

void epdWriteCommand(uint8_t cmd) {
    epdSelect();
    digitalWrite(PIN_EPD_DC, LOW);
    SPI.transfer(cmd);
    epdDeselect();
}

void epdWriteData(uint8_t data) {
    epdSelect();
    digitalWrite(PIN_EPD_DC, HIGH);
    SPI.transfer(data);
    epdDeselect();
}

// 调试命令 "dis <str>"：将字符串绘制到 6 色画布并整屏显示
int gui_drawtext(const char* str) {
    Paint_NewImage(BlackImage, EPD_WIDTH, EPD_HEIGHT, 0, NIBBLE_WHITE);
    Paint_SetScale(7);
    Paint_SelectImage(BlackImage);
    Paint_Clear(NIBBLE_WHITE);
    Paint_DrawString_EN(0, 0, str, &Font24, NIBBLE_BLACK, NIBBLE_WHITE);
    epdDisplayImage(BlackImage, ALLSCREEN_BYTES);
    return 0;
}

bool epdWaitBusy(uint32_t timeoutMs = 15000) {
    if (gIgnoreBusy) {
        return true;
    }

    uint32_t start = millis();
    const int busyLevel = gBusyActiveLevelLow ? LOW : HIGH;
    while (digitalRead(PIN_EPD_BUSY) == busyLevel) {
        // 省电：轮询间隔须 ≥ tickless idle 入睡阈值（8ms @ 1000Hz），
        // 否则等待 BUSY 期间 CPU 一直活跃（约 15mA），无法进入 light sleep
        delay(20);
        if (millis() - start > timeoutMs) {
            Serial.printf("[EPD] wait busy timeout, pin=%d, activeLow=%d\n",
                          digitalRead(PIN_EPD_BUSY), gBusyActiveLevelLow ? 1 : 0);
            return false;
        }
    }
    return true;
}

bool epdWaitBusyStage(const char* stage, uint32_t timeoutMs) {
    bool ok = epdWaitBusy(timeoutMs);
    if (!ok) {
        Serial.printf("[EPD] stage timeout: %s\n", stage);
    }
    return ok;
}

void epdReset() {
    digitalWrite(PIN_EPD_RST, LOW);
    delay(20);
    digitalWrite(PIN_EPD_RST, HIGH);
    delay(20);
    epdWaitBusy(BUSY_TIMEOUT_INIT_MS);
    delay(10);
}

void epdInitJD7601() {
    epdWriteCommand(0xE9);
    epdWriteData(0x01);
}
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

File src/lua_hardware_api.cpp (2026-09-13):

#include "lua_hardware_api.h"

#include <Arduino.h>
#include <FastLED.h>
#include <Preferences.h>
#include "esp_sleep.h"
#include "app_control.h"
#include "module_registry.h"
#include "sleep_manager.h"
#include "time_calibration.h"
#include "GUI_Paint.h"
#include "common.h"
#include "eink_display.h"

extern "C" {
#include "lua.h"
#include "lualib.h"
#include "lauxlib.h"
}

namespace {

// 全局重力数据快照（由调用者更新）
struct GravitySnapshot {
  float x, y, z;
  bool valid;
};

GravitySnapshot g_gravity_snapshot = {0, 0, 0, false};

// 资源使用标志
bool g_use_button = false;

// 按键事件回调
struct ButtonEvent {
  enum Type { NONE = 0, CLICK = 1, LONG_PRESS = 2 };
  Type type;
  uint32_t timestamp;
};

ButtonEvent g_button_event = {ButtonEvent::NONE, 0};
bool g_button_is_holding = false;  // 按键是否正在被按住
bool g_button_is_holding_used = false;  // 当前模块是否使用了 is_holding() 函数

}  // namespace


// 启动已声明的硬件资源
void lua_hardware_start_resources() {

}

// 停止所有硬件资源
void lua_hardware_stop_resources() {
  if (g_use_button) {
    Serial.println("Lua: Releasing button control...");
    g_use_button = false;
    g_button_event.type = ButtonEvent::NONE;
    g_button_is_holding = false;
    g_button_is_holding_used = false;  // 重置 is_holding 使用标志
  }
}
// ============================================================================
// Button API
// ============================================================================

// button.poll() -> returns event_type (0=none, 1=click, 2=long_press)
static int lua_button_poll(lua_State* L) {
  int event_type = (int)g_button_event.type;
  g_button_event.type = ButtonEvent::NONE;  // 清除事件
  lua_pushnumber(L, event_type);
  return 1;
}

// button.is_holding() -> returns true if button is currently being held
static int lua_button_is_holding(lua_State* L) {
  g_button_is_holding_used = true;  // 标记当前模块使用了 is_holding()
  lua_pushboolean(L, g_button_is_holding);
  return 1;
}

static const luaL_Reg button_lib[] = {
  {"poll", lua_button_poll},
  {"get_event", lua_button_poll},
  {"is_holding", lua_button_is_holding},
  {NULL, NULL}
};

// ============================================================================
// Config API
// ============================================================================

// config.get(key) -> returns int value
static int lua_config_get(lua_State* L) {
  const char* key = luaL_checkstring(L, 1);
  int value = load_config(key);
  lua_pushnumber(L, value);
  return 1;
}

static const luaL_Reg config_lib[] = {
  {"get", lua_config_get},
  {NULL, NULL}
};

// ============================================================================
// Time API
// ============================================================================

// time.millis() -> returns milliseconds since boot
static int lua_time_millis(lua_State* L) {
  lua_pushnumber(L, millis());
  return 1;
}

// time.delay(ms) -> blocking delay
static int lua_time_delay(lua_State* L) {
  unsigned long ms = luaL_checknumber(L, 1);
  delay(ms);
  return 0;
}

// time.get() -> returns hour, minute, second
static int lua_time_get(lua_State* L) {
  time_t now = TimeCalibration::get_calibrated_time();
  struct tm timeinfo;
  localtime_r(&now, &timeinfo);

  lua_pushinteger(L, timeinfo.tm_hour);
  lua_pushinteger(L, timeinfo.tm_min);
  lua_pushinteger(L, timeinfo.tm_sec);
  return 3;
}

// time.now() -> returns table with current time {year, month, day, hour, min, sec, wday}
static int lua_time_now(lua_State* L) {
  // 使用校准后的时间而不是原始系统时间
  time_t now = TimeCalibration::get_calibrated_time();
  struct tm timeinfo;
  localtime_r(&now, &timeinfo);

  lua_newtable(L);

  lua_pushinteger(L, timeinfo.tm_year + 1900);
  lua_setfield(L, -2, "year");

  lua_pushinteger(L, timeinfo.tm_mon + 1);
  lua_setfield(L, -2, "month");

  lua_pushinteger(L, timeinfo.tm_mday);
  lua_setfield(L, -2, "day");

  lua_pushinteger(L, timeinfo.tm_hour);
  lua_setfield(L, -2, "hour");

  lua_pushinteger(L, timeinfo.tm_min);
  lua_setfield(L, -2, "min");

  lua_pushinteger(L, timeinfo.tm_sec);
  lua_setfield(L, -2, "sec");

  lua_pushinteger(L, timeinfo.tm_wday);
  lua_setfield(L, -2, "wday");

  return 1;
}

static const luaL_Reg time_lib[] = {
  {"millis", lua_time_millis},
  {"delay", lua_time_delay},
  {"get", lua_time_get},
  {"now", lua_time_now},
  {NULL, NULL}
};

// ============================================================================
// Display API (e-ink)
// ============================================================================

// 前向声明（GB2312 中文字库渲染，定义于本文件后方）
static bool gb_map_load();
static void draw_utf8_text(int x, int y, const char* str, int cn_cell, sFONT* ascii_font,
                           UWORD color, bool fill_bg, UWORD bg_color);
static void draw_ascii_text_ex(int x, int y, const char* str, sFONT* font,
                               UWORD color, UWORD bg_color, bool fill_bg);

// 画布缓冲（4色屏定义于 eink.cpp，6色屏定义于 eink6.cpp）
extern unsigned char BlackImage[ALLSCREEN_BYTES];

// Lua 颜色值(0=黑,1=白,2=黄,3=红,4=蓝,5=绿) -> 画布颜色值
static UWORD lua_color_to_paint(int color) {
#ifdef INK6
  switch (color) {
    case 1:  return NIBBLE_WHITE;   // 白
    case 2:  return NIBBLE_YELLOW;  // 黄
    case 3:  return NIBBLE_RED;     // 红
    case 4:  return NIBBLE_BLUE;    // 蓝
    case 5:  return NIBBLE_GREEN;   // 绿
    case 0:
    default: return NIBBLE_BLACK;   // 黑
  }
#elif defined(INK_BW)
  // 黑白屏：浅色（黄）用抖动灰表现，深色（红/蓝/绿）转黑，保证内容可辨识
  switch (color) {
    case 1:  return WHITE;       // 白
    case 2:  return GRAY_LIGHT;  // 黄 -> 浅灰抖动
    case 0:
    case 3:
    case 4:
    default: return BLACK;       // 黑
  }
#else
  switch (color) {
    case 1:  return WHITE0;   // 白
    case 2:  return YELLOW0;  // 黄
    case 3:  return RED0;     // 红
    case 0:
    default: return BLACK0;   // 黑
  }
#endif
}

// 画布“白底”颜色（4色屏为 2bit 白，6色屏为 4bit 白半字节）
#if defined(INK6)
#define PAINT_BG_WHITE NIBBLE_WHITE
#elif defined(INK_BW)
#define PAINT_BG_WHITE WHITE
#else
#define PAINT_BG_WHITE WHITE0
#endif

static void display_prepare_canvas() {
#if defined(INK6)
  // 6 色屏：240x240，4bpp（2 像素/字节），直接对应 JD7601 帧格式
  Paint_NewImage(BlackImage, EPD_WIDTH, EPD_HEIGHT, 0, PAINT_BG_WHITE);
  Paint_SetScale(7);
#elif defined(INK_BW)
  // 黑白屏：200x200，1bpp（8 像素/字节）
  Paint_NewImage(BlackImage, EPD_WIDTH, EPD_HEIGHT, 0, PAINT_BG_WHITE);
  Paint_SetScale(2);
#else
  Paint_NewImage(BlackImage, EPD_WIDTH, EPD_HEIGHT, 0, WHITE0);
  Paint_SetScale(4);
#endif
  // 全局显示方向（模块页“显示方向”）：对 Lua 绘制模块统一生效
  Paint_SetRotate((UWORD)load_config_ns("gallery", "rotation"));
  Paint_SelectImage(BlackImage);
}

// display.clear()
static int lua_display_clear(lua_State* L) {
  display_prepare_canvas();
  Paint_Clear(PAINT_BG_WHITE);
  return 0;
}

// display.pixel(x, y, color)
static int lua_display_pixel(lua_State* L) {
  int x = (int)luaL_checknumber(L, 1);
  int y = (int)luaL_checknumber(L, 2);
  int c = (int)luaL_optnumber(L, 3, 0);
  display_prepare_canvas();
  Paint_SetPixel(x, y, lua_color_to_paint(c));
  return 0;
}
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

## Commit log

2026-08-01 首次提交
    [partitions.csv]
2026-08-02 墨水屏相册功能实现
    [gallery.cfg, partitions.csv]
2026-08-02 相册配置项优化
    [gallery.cfg]
2026-08-02 相册添加旋转功能
    [gallery.cfg]
2026-08-02 自动休眠前不必保存配置
2026-08-05 spi配置
2026-08-05 lua显示函数实现，中文字体支持，纪念日倒计时模块
    [countdown.cfg]
2026-08-07 新增white命令
2026-08-11 适配6色墨水屏版本硬件
2026-08-11 显示方向作为全局配置，从设备端拉取图片优化
    [gallery.cfg]
2026-08-11 分区表扩大
    [partitions.csv]
2026-08-12 优化图片传输速度
2026-08-12 刷新文档
2026-08-12 上下按键钩子，lua模块定时唤醒，时区修复
    [countdown.cfg]
2026-08-13 休眠状态上下键长短按逻辑优化
2026-08-14 发送刷新命令立即休眠，大大节省电量
2026-08-14 解决第一次能唤醒，以后无法唤醒问题
2026-08-14 蓝牙断开后立即休眠
2026-08-23 测量电池电量无需缓存
2026-08-27 扩大存储空间，统一休眠唤醒按键执行策略
    [countdown.cfg, partitions.csv]
2026-08-27 预加载中文字库
2026-08-28 white命令修复
2026-08-28 4色屏代码修复
2026-08-30 放电截止保护
2026-08-30 蓝牙省电配置
2026-08-30 优化蓝牙开启后总电流20mA
2026-08-30 优化蓝色灯电流
2026-08-30 优化非蓝牙开启功耗
2026-08-30 pioarduino 平台补丁：NimBLE + custom_sdkconfig 构建所需
2026-09-11 文字支持背景，安装模块写入默认休眠时间
    [countdown.cfg]
2026-09-13 黑白两色屏支持
2026-09-13 支持黑白2色屏，同时支持所有屏刷新期间mcu休眠
2026-09-13 2色屏支持局刷
2026-09-25 添加硬件设计
    [BOM.xlsx, Eink.PrjPcb, Eink1.1.PcbDoc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]
2026-09-25 文档更新
2026-09-26 补充图片
2026-09-26 添加step文件
    [墨水屏外壳.STEP]
